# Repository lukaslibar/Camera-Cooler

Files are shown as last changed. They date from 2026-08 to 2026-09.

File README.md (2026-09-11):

# Camera Cooler
Cooling solution for Svbony SV705C astronomy camera.

More about the project on my [website](https://luka.slibar.si/project.html?id=project1).

---

This repository contains multiple components, each under its own license.

- Firmware - GPL-3.0
- Hardware - CERN-OHL-S-2.0
- Software - GPL-3.0

See the ***project-folder/LICENSES*** directory for the full license texts.

---

This project is an attempt to actively cool the Svbony SV7505C astronomy camera. The cooling is intended to achieve better image quality by cooling the camera sensor through the bottom PCB. With this setup, we have achieved a temperature difference of 20°C, but we are still trying to improve the results through better insulation. A major problem is condensation, and great care must be taken to avoid short circuits on the camera's bottom PCB. The PCB manufactured by **JLCPCB** can either be placed upside down or sealed with rubber or a similar material. The cooling system is powered by a 19V DC power supply capable of supplying at least 6 A of current.

We are currently developing the REV B PCB, which will eliminate some issues with incorrect connectors (fen connectors) and add the ability to completely disable the Peltier element (TEC) (with an additional MOSFET). At the moment, there are MicroPython example programs for controlling the device, but we are developing a C++ driver to make the system faster and more efficient. There is also a simple GUI, but the USB port currently needs to be configured manually.

**PROBLEMS:**
- ~~Only 20°C of temperature difference(?broken TEC? Possible solution: change the TEC)~~ **with new TEC about 25°C*
- Condensation is accumulating after long periods of runing the device(Possible solution: improve insulation, heat the other side of the camera)
- ~~Slow response time (Possible solution: rewrite the driver in C++)~~  **still needs tuning*
- Noisy fan (Possible solution: change it for a slower fan or a Noctua fan)
- TEC always on (Solution: REV B of the PCB will have an ability to completely power it off)
- Openings on the camera-cooler.stl part are too small and so are hard to print (Solution: thicken them or copletely remove them)

---

## Instructions
### Tools
- PCB Assembly: hot air gun, soldering iron, solder paste, soldering wire, flux
- Whole assembly: 3d printer, screwdrivers (philips, inbus)

### Additional Parts (not on the PCB)
**TEC**
- 15V 5A Paltier element (TEC) 40mm square

**FANS**
- S4028-15K (**12V 40mm 4pin PC connector** (any simmilar fan will also work)) (to cool the heatsink)
- Generic **12V 40mm 2/3/4pin 10mm height** fan (to cool the enclosure) 

**HEATSINKS**
- 25×34×12mm TO-220 heatsink *(to cool the buck converter (XL4016E1) that powers the TEC)* [link](https://www.aliexpress.com/item/1005005843184927.html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)
- Aluminium motherboard heatsink for a 40mm fan [link](https://www.aliexpress.com/item/1005009277375992.html?spm=a2g0o.order_list.order_list_main.95.6b821802gXbK9t)

**THERMAL PAD AND PASTE**
- 100x100mm 1.0mm thick pad [link](https://www.aliexpress.com/item/32988894487.html?spm=a2g0o.order_list.order_list_main.55.6b821802gXbK9t)
- PC thermal paste

**THERMOMETER**
- DS18B20 (**2 are already in the BOM** but only one is currently integrated)

 **INTERFACE**
- **19V 6A** (at least) DC Power Supply with **2.54mm** barrel jack *(for power)* [link](https://www.aliexpress.com/item/1005004085574495.html?spm=a2g0o.order_list.order_list_main.90.6b821802gXbK9t)
- USB-C cable (for data and programming)
- **26 pin 0.5mm pitch 20cm** FFC(felxible flat cable) forward direction *(to inteface between two camera PCBs)* [link](https://www.aliexpress.com/item/1005008474655738.html?spm=a2g0o.order_list.order_list_main.60.6b821802gXbK9t)
- **3 pin-J Micro JST XH 2.54mm pitch** male plug with wire *(to connect the thermometer to the PCB)* [link](https://www.aliexpress.com/item/1005007107123815.html?spm=a2g0o.order_list.order_list_main.65.6b821802gXbK9t)

**SCREWS**
- **Screws:** 16 x M3x4 *(2 screws from the Svbony camera can be reused here, the other 2 are used to mount the camera-cooler.stl to the camera)*, 2/4 x M5x10 *(2 are sufficient, for mounting the enclosure fan)*, 2/4 x M5x47 *(2 are sufficient, for mounting the main fan to the heatsink)*, 7 x M2x5 *(to hold down both PCBs)*
- **Threaded inserts:** 16 x M3x5

### PCB
PCB assembly is quite straightforward. The only exception is soldering the XL4016E1 and its heatsink. They should first be screwed together with a small amount of thermal pad or thermal paste between them. The assembly should then be placed on the PCB and soldered in place at the same time to prevent misalignment.

### Assembly
First, the camera needs to be disassembled. Its top cover and upper PCB, which is connected with a short ribbon cable, need to be removed. The aluminium cooling block and the 3D-printed cooling block holder can then be assembled. The 3d printed parts screwholes should be inserted with threaded inserts with a soldering iron or simmilar tool.

Place a thermal pad on the smaller side of the cooling block. The thermal pad should be cut to the same shape as that side of the block. There is a small hole on the side of the block for the temperature sensor, which must have wires soldered to it. A longer ribbon cable should be connected to the bottom PCB. A small amount of thermal paste can be applied between the temperature sensor and the cooling block to ensure more accurate temperature readings.

The entire assembly can now be fitted into the camera enclosure so that the screw holes are properly aligned. The main fan and heatsink can then be screwed together, and the fan cable can be routed through the upper hole into the PCB enclosure. The complete fan and heatsink assembly can then be fitted into the main enclosure.

The Peltier element (TEC) needs to be fitted to the bottom of the heatsink, with thermal paste applied between the two surfaces. There are holes for its wires alongside a slit for the longer ribbon cable. The camera and the cooler can then be joined together using thermal paste between their contact surfaces. The upper camera PCB and the custom TEC driver PCB have designated positions inside the enclosure on the side. An additional fan can also be installed to cool the enclosure.

---

### Electrical Connections
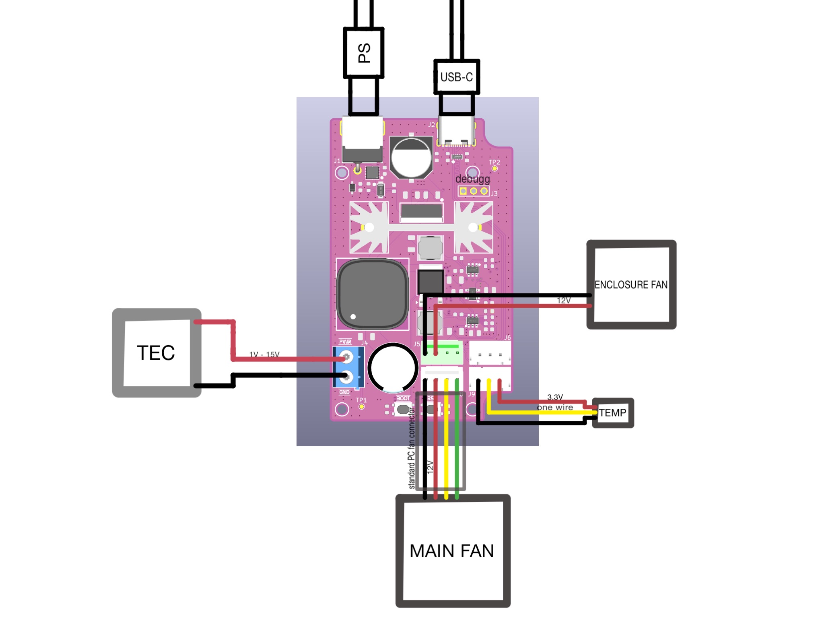
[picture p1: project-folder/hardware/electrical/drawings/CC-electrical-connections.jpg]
TEC driver electrical connections

*TEC driver electrical connections*

---

### Mechanical Assembly
Assembly of 3d printed parts
*Assembly of 3d-printed parts and pcb*

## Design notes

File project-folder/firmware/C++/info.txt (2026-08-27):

The programmes require Raspberry Pico SDK to compile.
Information on how to setup the SDK on:
https://pip-assets.raspberrypi.com/categories/610-raspberry-pi-pico/documents/RP-008276-DS-2-getting-started-with-pico.pdf

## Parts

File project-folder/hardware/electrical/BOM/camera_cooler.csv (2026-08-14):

Reference | Qty | Value | DNP | Exclude from BOM | Exclude from Board | LCSC | Manufacturer | Mauser | Part | Description
C1,C12 | 2 | 22u |  |  |  | C7432786 | Chinocera |  | HGC1206R5226M250NSPJ | 22uF ±20% 25V Ceramic Capacitor X5R 1206
C2,C3,C4,C5,C6,C10,C14,C21,C22,C23,C24,C25,C26,C27,C28,C29,C30,C31,C32,C33,C43 | 21 | 100n |  |  |  | C6119867 | muRata |  | CGA0603X7R104K500JT | 100nF ±10% 50V Ceramic Capacitor X7R 0603
C7 | 1 | 4.7u |  |  |  | C77096 | muRata |  | GRM31CR71H475KA12L | 4.7uF ±10% 50V Ceramic Capacitor X7R 1206
C8,C9,C13,C34,C44,C45,C46 | 7 | 10u |  |  |  | C440198 | muRata |  | GRM21BR61H106KE43L | 10uF ±10% 50V Ceramic Capacitor X5R 0805
C11 | 1 | 47p |  |  |  | C5137501 | FOJAN |  | FCC0603N470J500CT | 47pF ±5% 50V Ceramic Capacitor C0G 0603
C15,C16,C19,C20 | 4 | 4.7u |  |  |  | C19666 | Samsung Electro-Mechanics |  | CL10A475KO8NNNC | 4.7uF ±10% 16V Ceramic Capacitor X5R 0603
C17,C18 | 2 | 15p |  |  |  | C519483 | YAGEO |  | CC0603FRNPO9BN150 | 15pF ±1% 50V Ceramic Capacitor NP0 0603
C36,C37,C41 | 3 | 1u |  |  |  | C1848 | Samsung Electro-Mechanics |  | CL31B105KBHNNNE | 1uF ±10% 50V Ceramic Capacitor X7R 1206
C38 | 1 | 470u |  |  |  | C22469994 | FOLLON |  | EFVM050ADA471M10C0 | 470uF ±20% 50V Aluminum Electrolytic Capacitors
C39 | 1 | 33n |  |  |  | C21117 | Samsung Electro-Mechanics |  | CL10B333KB8NNNC | 33nF ±10% 50V Ceramic Capacitor X7R 0603
C40 | 1 | 1000u |  |  |  | C88743 | rubycon |  | 35YXJ1000M12.5X20 | 1000uF 35V Aluminum Electrolytic Capacitors Through Hole,D12.5xL20mm 10000hrs@105℃
D1 | 1 | PESD1IVN24-AX |  |  |  | C503381 | Nexperia |  | PESD1IVN24-AX | 42VC Clamp 3.5A@8/20us Ipp ESD DIODE SOD-323
D2 | 1 | MMSZ4706_C3031903 |  |  |  | C3031903 | CJ |  | MMSZ4706 | Zener Diode Independent 19V 500mW Surface Mount SOD-123
D3 | 1 | TPD4E05U06DQAR_C2827646 |  |  |  | C2827646 | TECH PUBLIC |  | TPD4E05U06DQAR | 13VC Clamp 5A Ipp ESD DIODE USON-10(1x2.5)
D4 | 1 | MBR2045DCT |  |  |  | C42402358 | BORN |  | MBR2045DCT | Diode 45V 20A Surface Mount TO-252
J1 | 1 | DC-044K-D025 |  |  |  | C963204 | G-Switch |  | DC-044K-D025 | Power Barrel Connector Jack 2.5mm ID 6mm OD Through Hole, Right Angle
J2 | 1 | TYPE-C 16PIN 2MD |  |  |  | C2765186 | SHOU HAN(首韩) |  | TYPE-C 16PIN 2MD(073) | USB-C (USB TYPE-C) Receptacle Connector 16 Position Surface Mount, Right Angle
J4 | 1 | KF301-5.0-2P |  |  |  | C474881 | KEFA |  | KF301-5.0-2P | 2 Position Wire to Board Terminal Block Through Hole 5mm
J5,J8 | 2 | 2510-4A |  |  |  | C2847671 | CAX |  | 2510-4A | Connector Header 4 position 2.54mm Pitch 3A Through Hole -25℃~+85℃
J6,J9 | 2 | ZX-XH2.54-3PZZ |  |  |  | C7429633 | Megastar |  | ZX-XH2.54-3PZZ | Connector Header 3 position 2.5mm Pitch 3A Through Hole -25℃~+85℃
L1 | 1 | 22u |  |  |  | C780213 | BOURNS |  | SRN6045-220M | 1.5A 22uH 142mΩ 1.9A ±20% SMD,6x6mm Fixed Inductors RoHS
L2 | 1 | 10u |  |  |  | C476261 | BOURNS |  | SRN6045-100M | 2.5A 10uH 3A 58.6mΩ ±20% SMD,6x6mm Fixed Inductors RoHS
L3 | 1 | 3.3u |  |  |  | C42411119 | ABRACON |  | AOTA-B201610S3R3-101-T | 2.1A 3.3uH 115mΩ 2.4A Molded Inductor 0806 Fixed Inductors RoHS
L4 | 1 | 47u |  |  |  | C5119635 | PROD |  | PDPMAA1712-470MP | 8A 47uH ±20% 32mΩ 14A Through Hole,P=13mm Fixed Inductors RoHS
Q1 | 1 | DMP3013SFV-7 |  |  |  | C264098 | Diodes |  | DMP3013SFV-7 | P-Channel 30V 35A 1.94W Surface Mount PowerDI3333-8
Q2,Q3 | 2 | 2N7002LT1G |  |  |  | C16338 | onsemi |  | 2N7002LT1G | N-Channel 60V 115mA 225mW Surface Mount SOT-23
R1 | 1 | 88.7k |  |  |  | C23258 | UNI-ROYAL |  | 0603WAF8872T5E | 88.7kΩ ±1% 100mW 0603 Thick Film Resistor
R2 | 1 | 22.1k |  |  |  | C2960862 | FOJAN |  | FRC0603F2212TS | 22.1kΩ ±1% 100mW 0603 Thick Film Resistor
R3,R8,R9,R15,R16 | 5 | 12k |  |  |  | C2907097 | FOJAN |  | FRC0603J123 TS | TS 12kΩ ±5% 100mW 0603 Thick Film Resistor
R4,R30,R33 | 3 | 100k |  |  |  | C2906980 | FOJAN |  | FRC0603F1003TS | 100kΩ ±1% 100mW 0603 Thick Film Resistor
R5 | 1 | 5.23k |  |  |  | C23068 | UNI-ROYAL |  | 0603WAF5231T5E | 5.23kΩ ±1% 100mW 0603 Thick Film Resistor
R6,R10,R13,R14 | 4 | 5.1k |  |  |  | C2907044 | FOJAN |  | FRC0603F5101TS | 5.1kΩ ±1% 100mW 0603 Thick Film Resistor
R7 | 1 | 33 |  |  |  | C2909394 | FOJAN |  | FRC0603F33R0TS | 33Ω ±1% 100mW 0603 Thick Film Resistor
R11,R12 | 2 | 27 |  |  |  | C2907021 | FOJAN |  | FRC0603F27R0TS | 27Ω ±1% 100mW 0603 Thick Film Resistor
R17,R18,R19 | 3 | 1k |  |  |  | C2907002 | FOJAN |  | FRC0603F1001TS | 1kΩ ±1% 100mW 0603 Thick Film Resistor
R20,R22 | 2 | 10 |  |  |  | C2906983 | FOJAN |  | FRC0603F10R0TS | 10Ω ±1% 100mW 0603 Thick Film Resistor
R21 | 1 | 2m |  |  |  | C46634447 | JIERR |  | JER2512F3R002 | 3W 2mΩ ±50ppm/℃ ±1% 2512 Chip Resistor - Surface Mount RoHS
R23 | 1 | 180k |  |  |  | C2906999 | FOJAN |  | FRC0603F1803TS | 180kΩ ±1% 100mW 0603 Thick Film Resistor
R24 | 1 | 43k |  |  |  | C2907038 | FOJAN |  | FRC0603F4302TS | 43kΩ ±1% 100mW 0603 Thick Film Resistor
R25,R27 | 2 | 0 |  |  |  | C2906974 | FOJAN |  | FRC0603F0000TS | 100mW 0Ω 75V Thick Film Resistor ±1% 0603 Chip Resistor - Surface Mount RoHS
R26 | 1 | 27k |  |  |  | C2930084 | FOJAN |  | FRC0603F2702TS | 27kΩ ±1% 100mW 0603 Thick Film Resistor
R28,R29,R31,R32 | 4 | 100 |  |  |  | C2906981 | FOJAN |  | FRC0603F1000TS | 100Ω ±1% 100mW 0603 Thick Film Resistor
SW1,SW2 | 2 | TS3425BA |  |  |  | C2681476 | SHOU HAN |  | TS3425BA | Tactile Switch SPST 250gf 2.5mm J-Lead 4.2mm x 3.2mm Surface Mount
U1,U2 | 2 | DS18B20 |  |  | Excluded from board | C9753 | MAXIM |  | DS18B20+ | -55℃~+125℃ ±0.5℃ Single bus 3V~5.5V TO-92 Analog and Digital Output RoHS
U4 | 1 | TPS560430XDBVR |  |  |  | C524782 | TI |  | TPS560430XDBVR | 1.1MHz Buck Adjustable 600mA 1V~34.2V SOT-23-6 Voltage Regulators - DC DC Switching Regulators RoHS
U5 | 1 | TLV75533PDBVR |  |  |  | C404027 | TI |  | TLV75533PDBVR | 3.3V Positive Fixed SOT-23-5 Voltage Regulators - Linear, Low Drop Out (LDO) Regulators RoHS
U6 | 1 | TPS54202DDCR |  |  |  | C191884 | TI |  | TPS54202DDCR | 500kHz Buck Adjustable 2A SOT-23-6 Voltage Regulators - DC DC Switching Regulators RoHS
U7 | 1 | RP2354A |  |  |  | C41378174 | Raspberry Pi |  | RP2354A | QFN-60(7x7) Microcontrollers RoHS
U8 | 1 | ABM8-272-T3_C20625731 |  |  |  | C20625731 | ABRACON |  | ABM8-272-T3 | ±30ppm 10pF ±30ppm SMD3225-4P Crystals RoHS
U9 | 1 | INA219AIDR |  |  |  | C138706 | TI |  | INA219AIDR | 0V~26V 10uV 20nA 1 SOIC-8 Current Regulation/Management RoHS
U10 | 1 | XL4016E1 |  |  |  | C55881 | XLSEMI |  | XL4016E1 | Buck Switching Regulator IC Adjustable 1.25V~32V 1 Output 12A TO-220-5
U11 | 1 | MCP4725A0T-E/CH |  |  |  | C144198 | MICROCHIP |  | MCP4725A0T-E/CH | 6us 2.7V~5.5V 2LSB I2C SOT-23-6 Digital to Analog Converters (DAC) RoHS

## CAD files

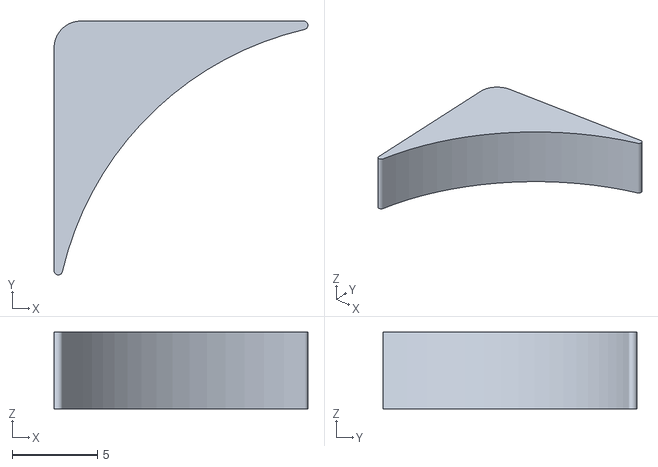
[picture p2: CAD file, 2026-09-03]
project-folder/hardware/mechanical/3d-printed/fan-spacer-TPU.STL
14.9 x 14.9 x 4.50

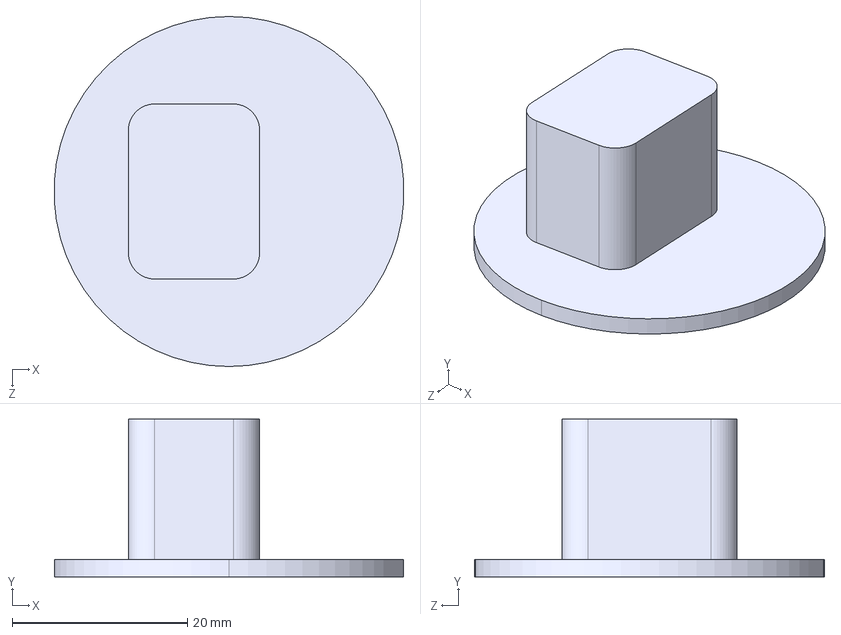
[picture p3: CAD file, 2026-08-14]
project-folder/hardware/mechanical/CNC/cooling_block_V2.STEP
39.9 x 18.0 x 40.0 mm

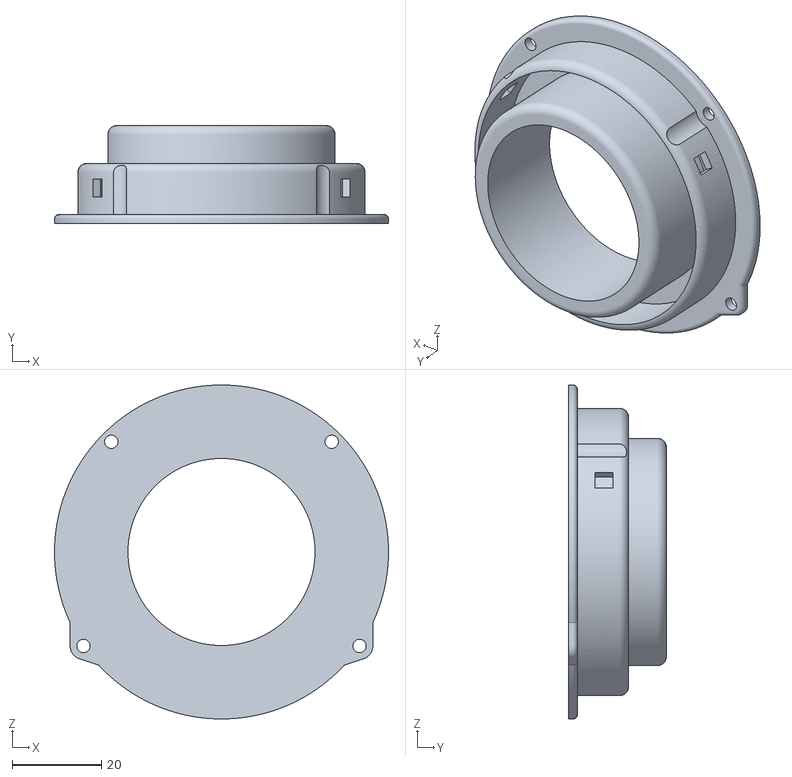
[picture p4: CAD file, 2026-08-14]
project-folder/hardware/mechanical/3d-printed/connection-mount.STL
75.0 x 22.0 x 75.0

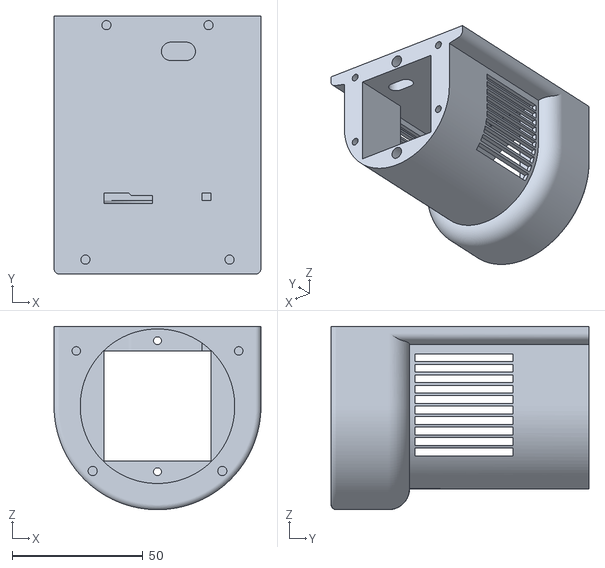
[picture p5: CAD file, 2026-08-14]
project-folder/hardware/mechanical/3d-printed/camera-cooler.STL
79.0 x 98.5 x 70.0

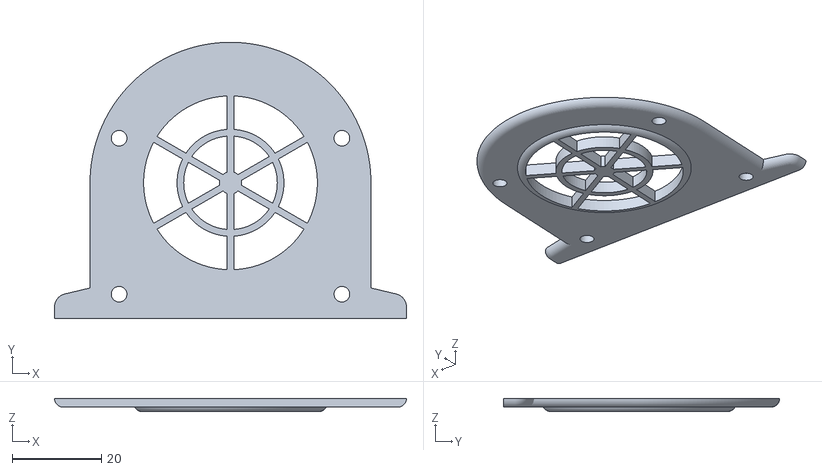
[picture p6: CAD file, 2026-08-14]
project-folder/hardware/mechanical/3d-printed/camera-cooler-cover.STL
79.0 x 62.0 x 3.00

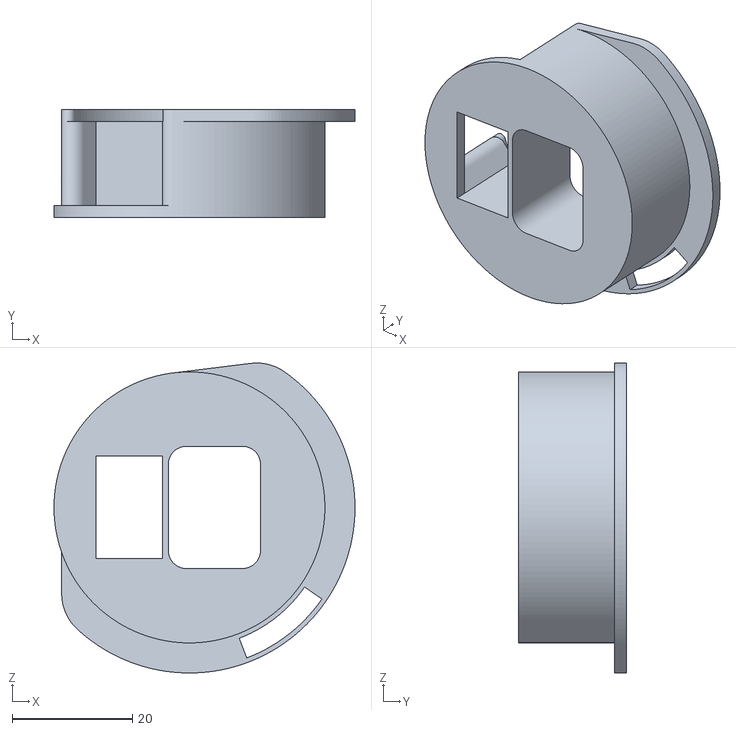
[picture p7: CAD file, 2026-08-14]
project-folder/hardware/mechanical/3d-printed/cooling-block-holder.STL
50.0 x 18.0 x 51.5

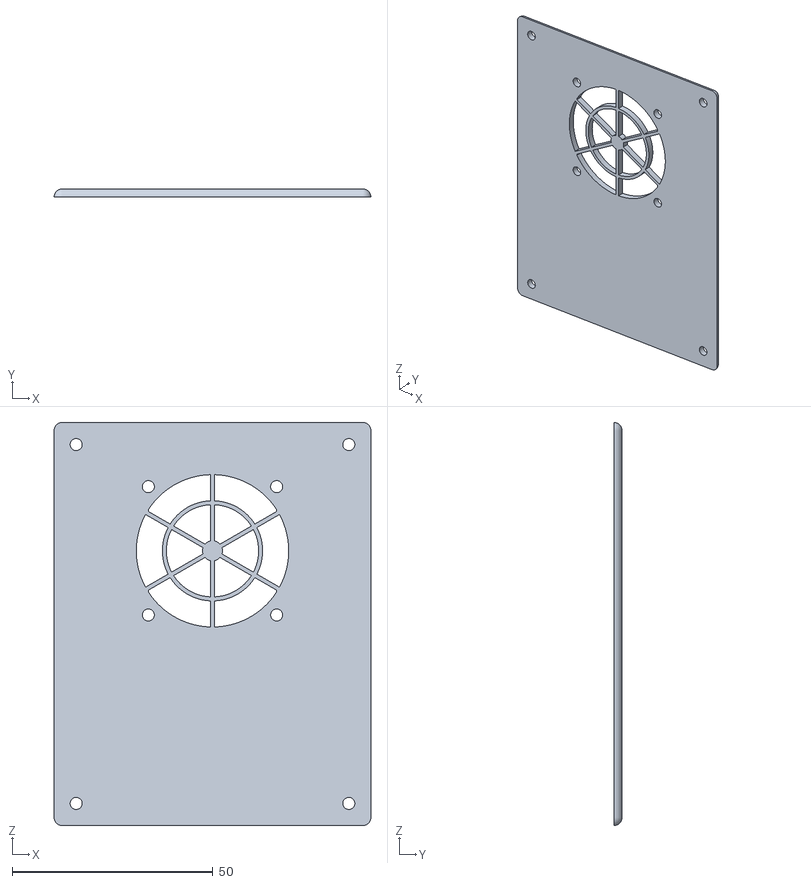
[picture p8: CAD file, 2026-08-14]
project-folder/hardware/mechanical/3d-printed/camera-cooler-enclosure-cover.STL
79.0 x 2.00 x 100.5

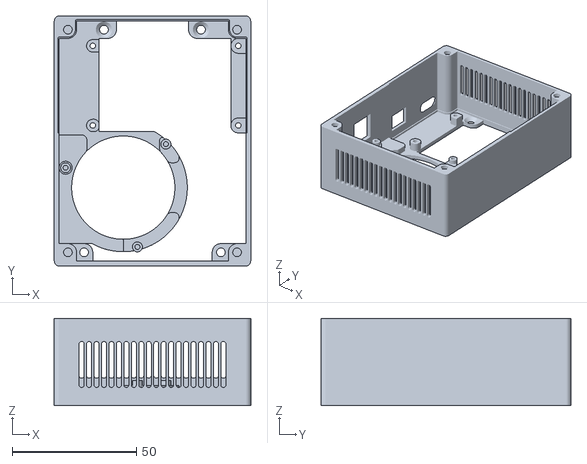
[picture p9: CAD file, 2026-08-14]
project-folder/hardware/mechanical/3d-printed/camera-cooler-enclosure.STL
79.0 x 100.5 x 35.0

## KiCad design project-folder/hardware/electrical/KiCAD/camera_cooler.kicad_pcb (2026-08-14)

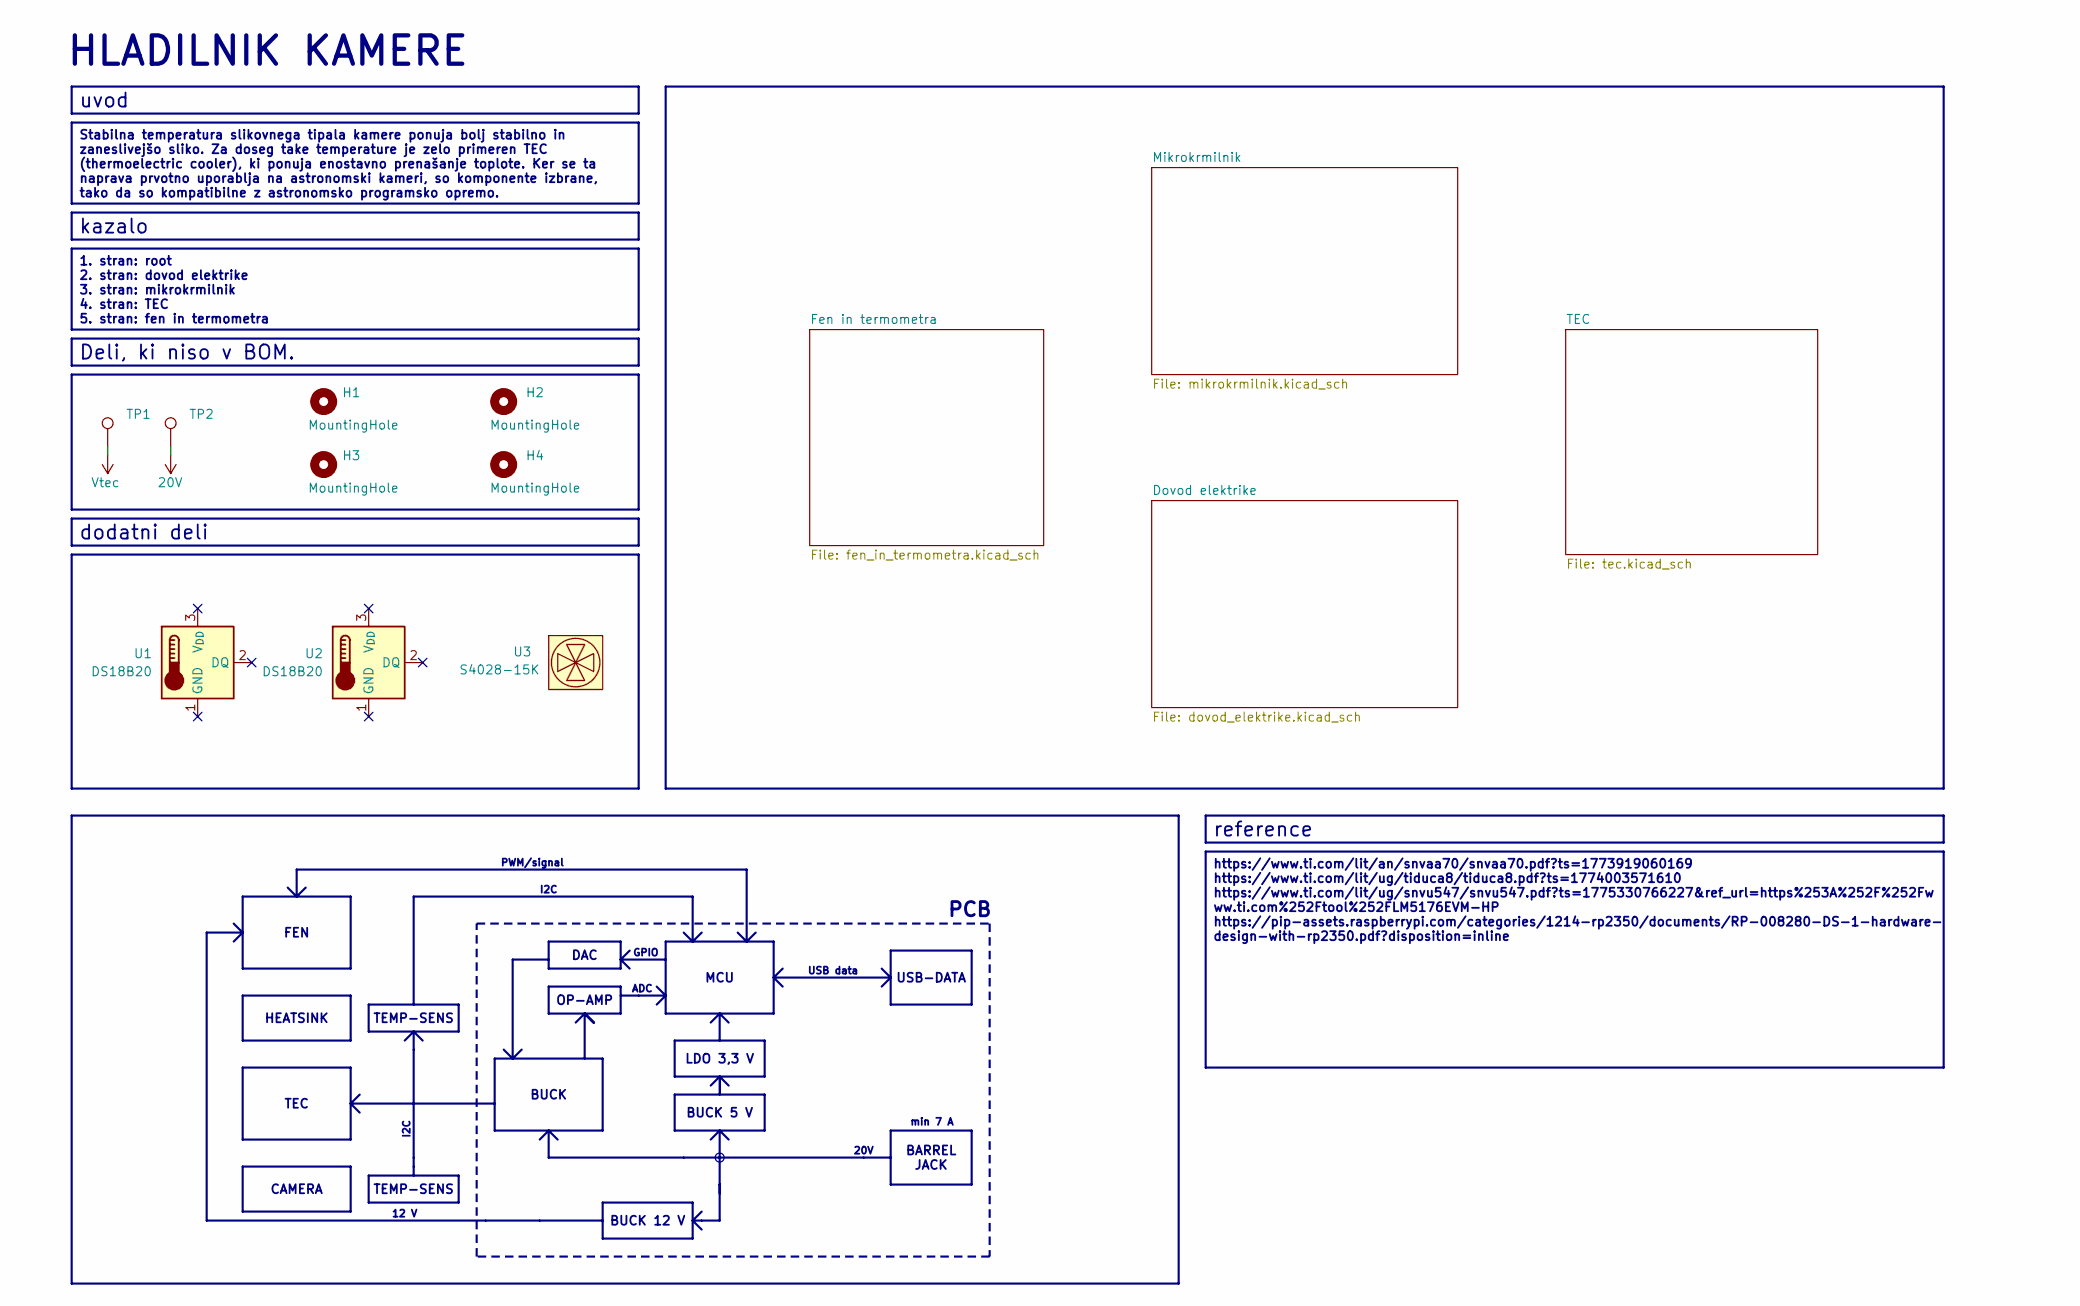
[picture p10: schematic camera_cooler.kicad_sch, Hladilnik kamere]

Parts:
H1, H2, H3, H4: MountingHole; MountingHole_2.2mm_M2
TP1, TP2: TestPoint; TestPoint_Pad_D1.0mm
U1, U2: DS18B20; TO-92_Inline; Part DS18B20+; LCSC C9753
U3: S4028-15K; Part S4028-15K

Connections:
20V: TP2.1; also elsewhere on the board
Vtec: TP1.1; also elsewhere on the board

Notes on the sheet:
GPIO
PCB
USB data
HLADILNIK KAMERE
min 7 A
20V
PWM/signal
I2C
12 V
ADC
MCU
reference
TEC
BUCK 12 V
FEN
HEATSINK
1. stran: root 2. stran: dovod elektrike 3. stran: mikrokrmilnik 4. stran: TEC 5. stran: fen in termometra
BUCK 5 V
BARREL JACK
https://www.ti.com/lit/an/snvaa70/snvaa70.pdf?ts=1773919060169 https://www.ti.com/lit/ug/tiduca8/tiduca8.pdf?ts=1774003571610 https://www.ti.com/lit/ug/snvu547/snvu547.pdf?ts=1775330766227&ref_url=https%253A%252F%252Fw ww.ti.com%252Ftool%252FLM5176EVM-HP https://pip-assets.raspberrypi.com/categorie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
Stabilna temperatura slikovnega tipala kamere ponuja bolj stabilno in zaneslivejšo sliko. Za doseg take temperature je zelo primeren TEC (thermoelectric cooler), ki ponuja enostavno prenašanje toplote. Ker se ta naprava prvotno uporablja na astronomski kameri, so komponente izbrane, tako da so komp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
OP-AMP
dodatni deli
Deli, ki niso v BOM.
kazalo
TEMP-SENS
USB-DATA
CAMERA
LDO 3,3 V
BUCK
uvod
DAC

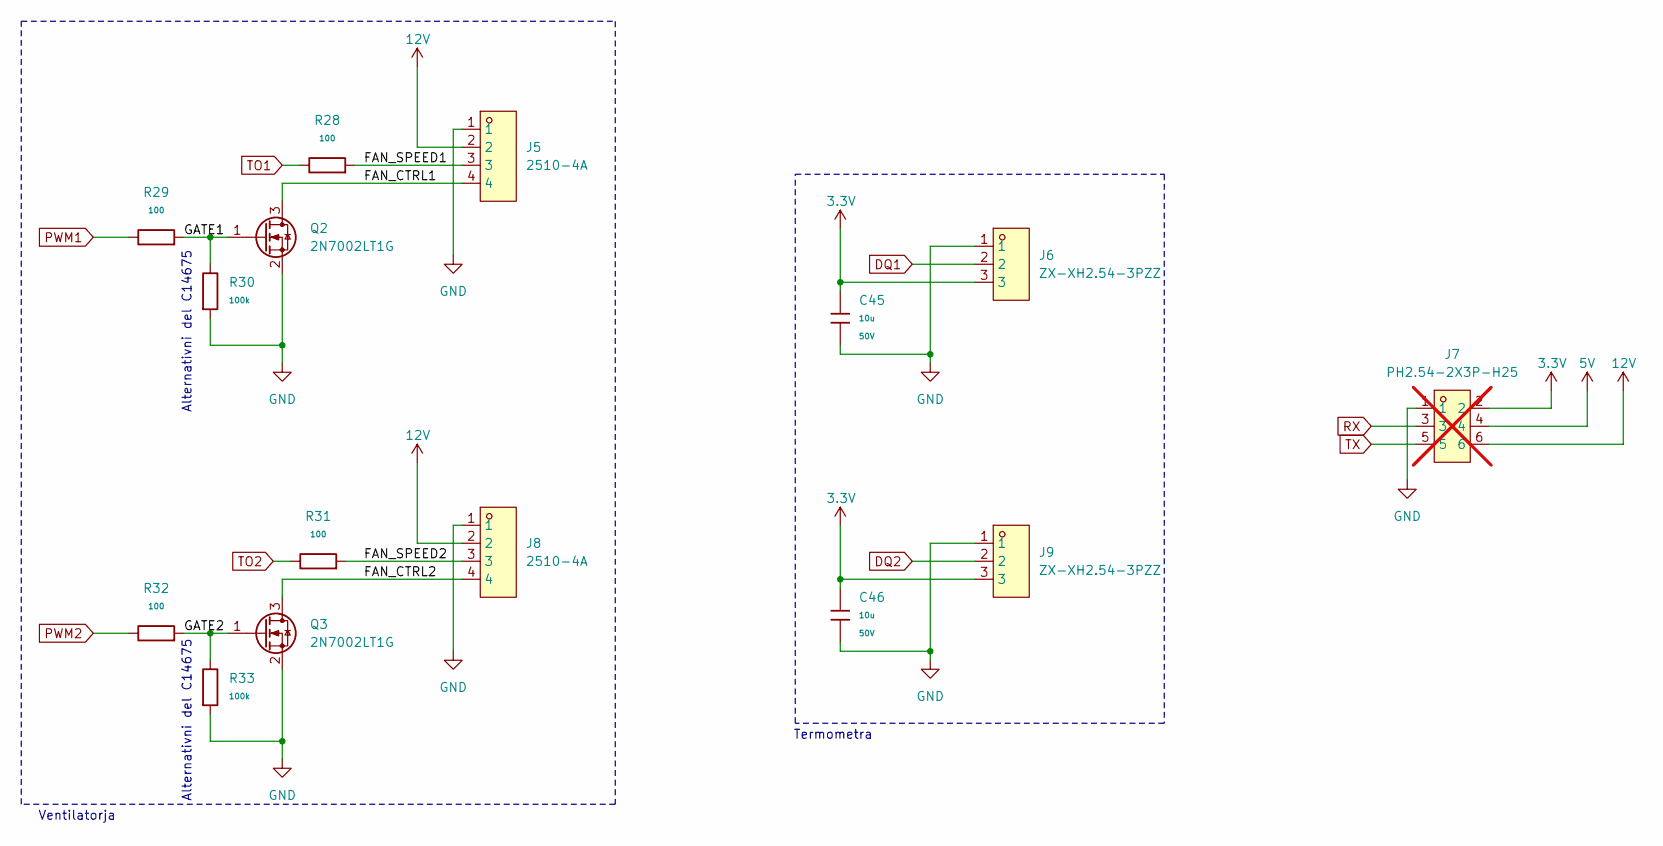
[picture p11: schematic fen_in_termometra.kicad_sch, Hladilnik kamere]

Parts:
C45, C46: 10u; C_0805; Voltage Rated 50V; Part GRM21BR61H106KE43L; LCSC C440198
J5, J8: 2510-4A; CONN-TH_4P-P2.54_CAX_2510-4A; MPN 2510-4A; LCSC Part C2847671
J6, J9: ZX-XH2.54-3PZZ; CONN-TH_3P-P2.54_2501S-3P; MPN ZX-XH2.54-3PZZ; LCSC Part C7429633
J7: PH2.54-2X3P-H25; HDR-TH_6P-P2.54-V-M-R2-C3-S2.54-1; MPN PH2.54-2X3P-H25; LCSC Part C42431837; not fitted
Q2, Q3: 2N7002LT1G; SOT-23; Part 2N7002LT1G; LCSC C16338
R28, R29, R31, R32: 100; R_0603; Part FRC0603F1000TS; LCSC C2906981
R30, R33: 100k; R_0603; Part FRC0603F1003TS; LCSC C2906980

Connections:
3.3V: C45.1, C46.1, J6.3, J7.2, J9.3; also elsewhere on the board
12V: J5.2, J7.6, J8.2; also elsewhere on the board
/Fen in termometra/GATE1: Q2.1 (G), R29.2, R30.1
/Fen in termometra/GATE2: Q3.1 (G), R32.2, R33.1
DQ1: J6.2; also elsewhere on the board
DQ2: J9.2; also elsewhere on the board
GND: C45.2, C46.2, J5.1, J6.1, J7.1, J8.1, J9.1, Q2.2 (S), Q3.2 (S), R30.2, R33.2; also elsewhere on the board
unnamed: J5.3, R28.2
unnamed: J8.3, R31.2
unnamed: J5.4, Q2.3 (D)
unnamed: J8.4, Q3.3 (D)
PWM1: R29.1; also elsewhere on the board
PWM2: R32.1; also elsewhere on the board
TO1: R28.1; also elsewhere on the board
TO2: R31.1; also elsewhere on the board

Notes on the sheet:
Ventilatorja
Alternativni del C14675
Termometra

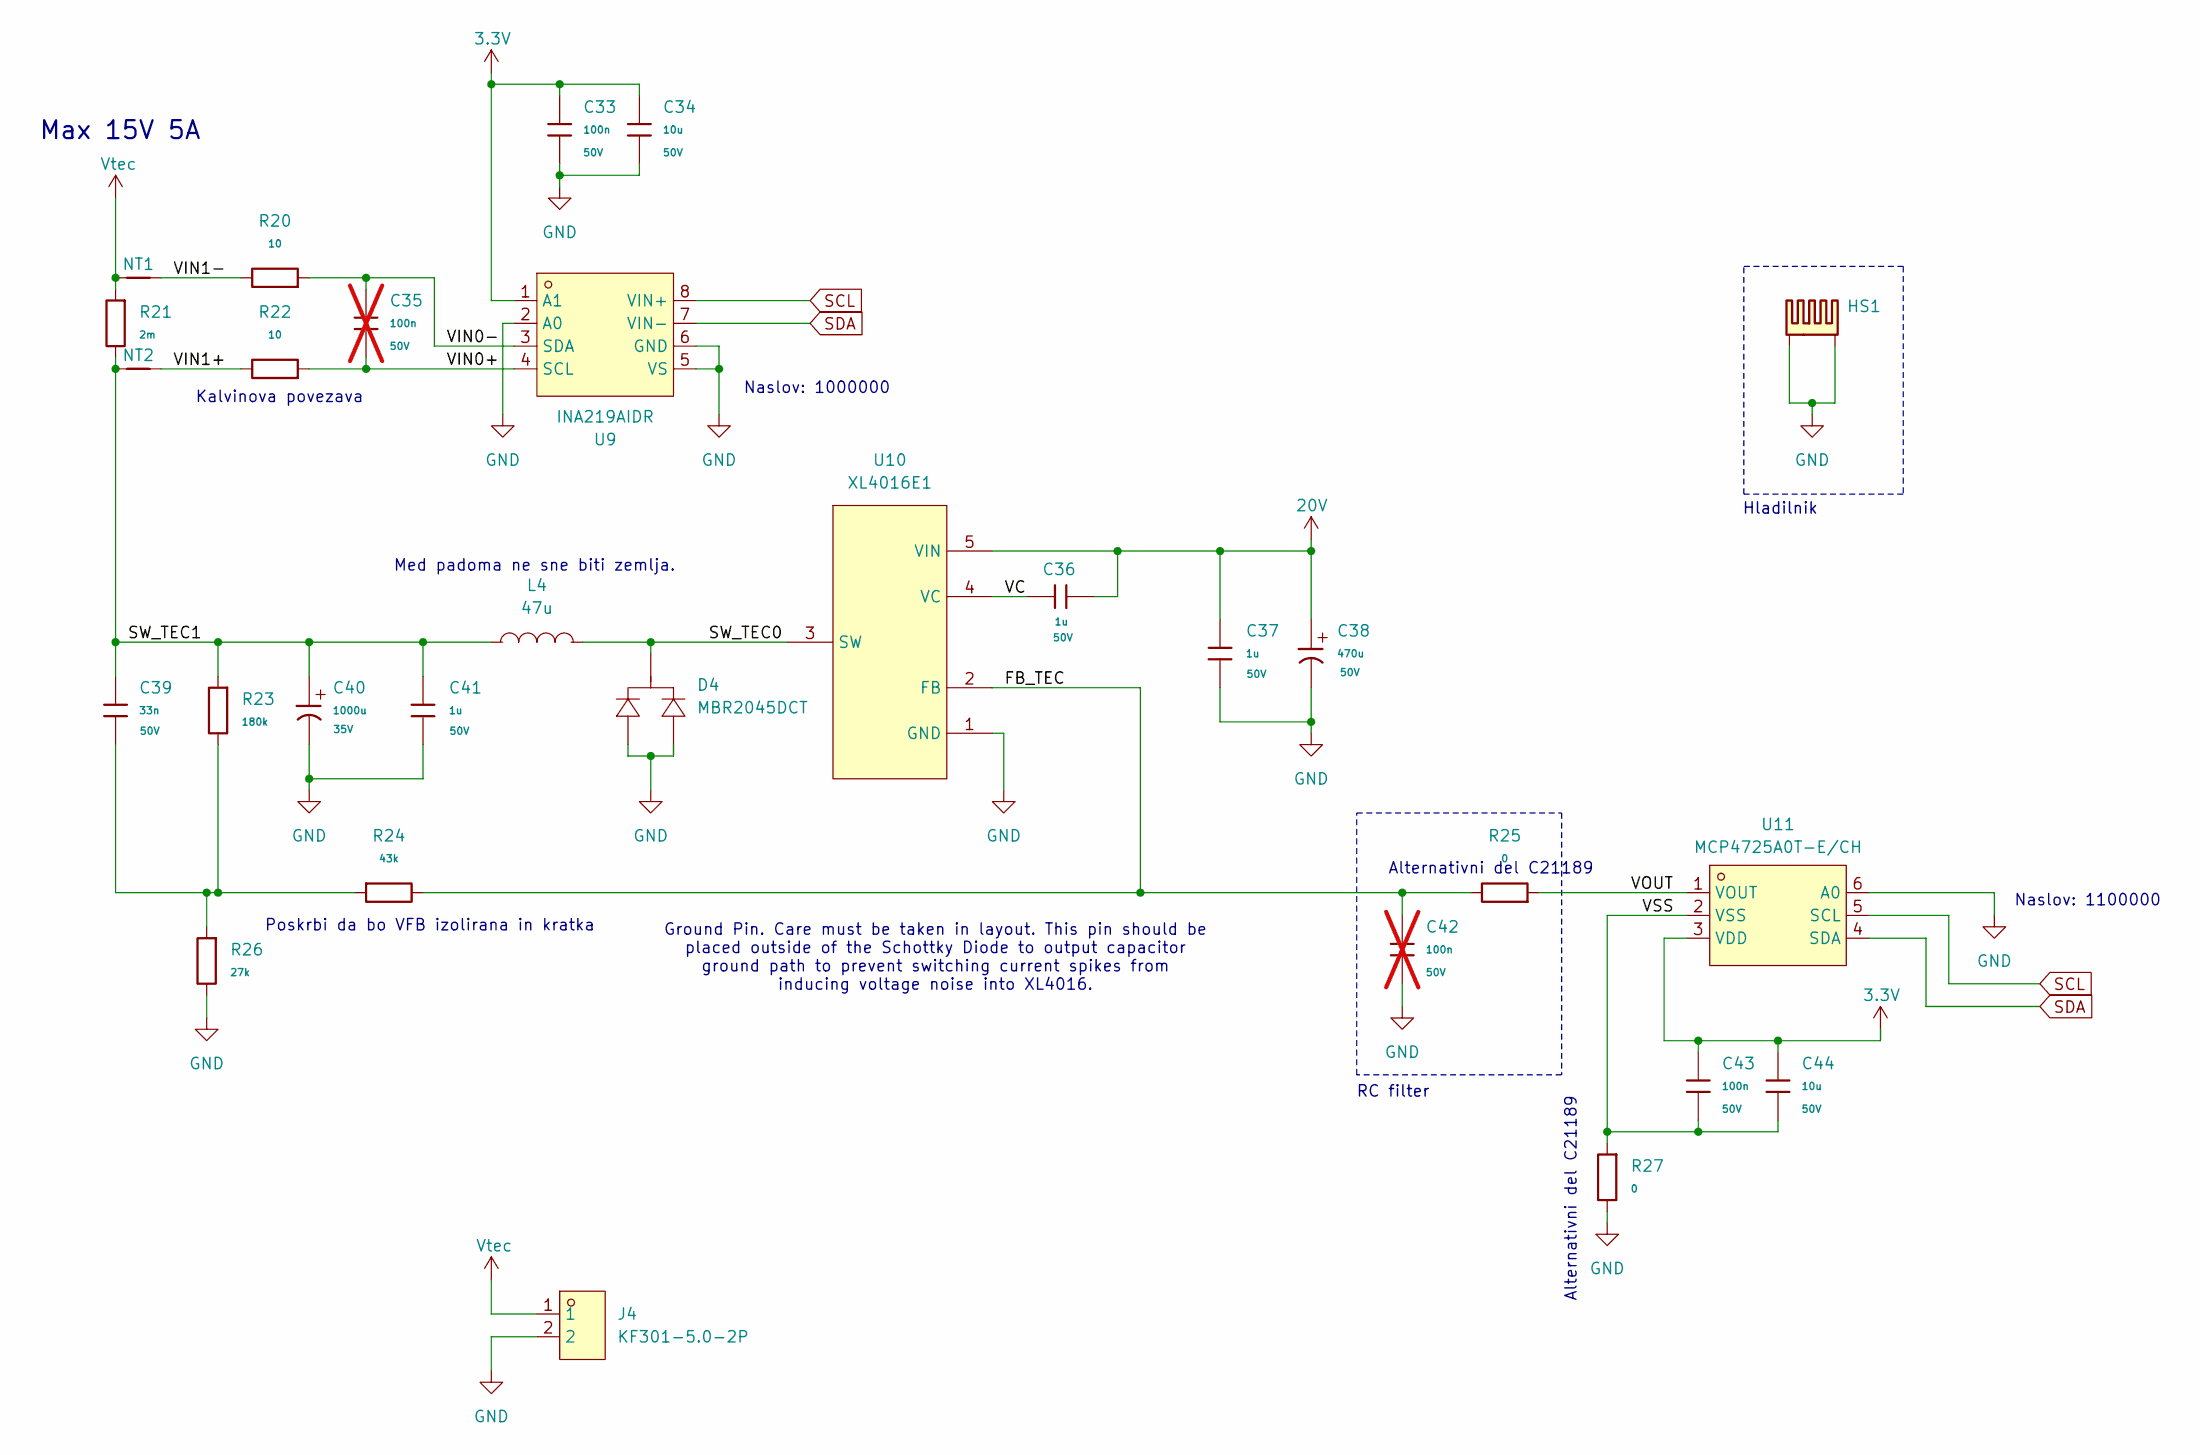
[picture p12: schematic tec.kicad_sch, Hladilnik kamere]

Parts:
C33, C43: 100n; C_0603; Voltage Rated 50V; Part CGA0603X7R104K500JT; LCSC C6119867
C34, C44: 10u; C_0805; Voltage Rated 50V; Part GRM21BR61H106KE43L; LCSC C440198
C35, C42: 100n; C_0603; Voltage Rated 50V; Tolerance ±10%; Part CGA0603X7R104K500JT; LCSC C6119867; not fitted
C36, C37, C41: 1u; C_1206; Voltage Rated 50V; Part CL31B105KBHNNNE; LCSC C1848
C38: 470u; CAP-SMD_BD10.0-L10.4-W10.4-LS11.2-FD; Voltage Rated 50V; Part EFVM050ADA471M10C0; LCSC C22469994
C39: 33n; C_0603; Voltage Rated 50V; Part CL10B333KB8NNNC; LCSC C21117
C40: 1000u; CAP-TH_BD12.5-P5.00-D0.6-FD; Voltage Rated 35V; Part 35YXJ1000M12.5X20; LCSC C88743
D4: MBR2045DCT; TO-252-2; Part MBR2045DCT; LCSC C42402358
HS1: HSE-B20254-035H-01; HSEB20254035H01; Part HSE-B20254-035H-01
J4: KF301-5.0-2P; CONN-TH_P5.00_KF301-5.0-2P; MPN KF301-5.0-2P; LCSC Part C474881
L4: 47u; IND-TH_L17.8-W17.8-P13.00-D0.6; Part PDPMAA1712-470MP; LCSC C5119635
NT1, NT2: NetTie_2; NetTie-2_SMD_Pad0.5mm
R20, R22: 10; R_0603; Part FRC0603F10R0TS; LCSC C2906983
R21: 2m; R_2512_6332Metric; Part JER2512F3R002; LCSC C46634447
R23: 180k; R_0603; Part FRC0603F1803TS; LCSC C2906999
R24: 43k; R_0603; Part FRC0603F4302TS; LCSC C2907038
R25, R27: 0; R_0603; Part FRC0603F0000TS; LCSC C2906974
R26: 27k; R_0603; Part FRC0603F2702TS; LCSC C2930084
U9: INA219AIDR; SOIC-8_L4.9-W3.9-P1.27-LS6.0-BL; MPN INA219AIDR; LCSC Part C138706
U10: XL4016E1; TO-220-5L_L10.2-W4.5-P1.71-L; Part XL4016E1; LCSC C55881
U11: MCP4725A0T-E/CH; SOT-23-6_L2.9-W1.6-P0.95-LS2.8-BL; MPN MCP4725A0T-E/CH; LCSC Part C144198

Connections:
3.3V: C33.1, C34.1, C43.1, C44.1, U9.1 (A1), U11.3 (VDD); also elsewhere on the board
20V: C36.2, C37.1, C38.1, U10.5 (VIN); also elsewhere on the board
/TEC/FB_TEC: C42.1, R24.1, R25.1, U10.2 (FB)
/TEC/SW_TEC0: D4.2, L4.2, U10.3 (SW)
/TEC/SW_TEC1: C39.1, C40.1, C41.1, L4.1, NT2.1, R21.1, R23.2
/TEC/VC: C36.1, U10.4 (VC)
/TEC/VIN0+: C35.2, R22.2, U9.4 (SCL)
/TEC/VIN0-: C35.1, R20.2, U9.3 (SDA)
/TEC/VIN1+: NT2.2, R22.1
/TEC/VIN1-: NT1.2, R20.1
/TEC/VOUT: R25.2, U11.1 (VOUT)
/TEC/VSS: C43.2, C44.2, R27.2, U11.2 (VSS)
GND: C33.2, C34.2, C37.2, C38.2, C40.2, C41.2, C42.2, D4.1, D4.3, HS1.1, HS1.2, J4.2, R26.1, R27.1, U9.2 (A0), U9.5 (VS), U9.6 (GND), U10.1 (GND), U11.6 (A0); also elsewhere on the board
unnamed: C39.2, R23.1, R24.2, R26.2
SCL: U9.8 (VIN+), U11.5 (SCL); also elsewhere on the board
SDA: U9.7 (VIN-), U11.4 (SDA); also elsewhere on the board
Vtec: J4.1, NT1.1, R21.2; also elsewhere on the board

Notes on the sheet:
Ground Pin. Care must be taken in layout. This pin should be placed outside of the Schottky Diode to output capacitor ground path to prevent switching current spikes from inducing voltage noise into XL4016.
Naslov: 1000000
Hladilnik
Naslov: 1100000
Kalvinova povezava
Poskrbi da bo VFB izolirana in kratka
Alternativni del C21189
Med padoma ne sne biti zemlja.
RC filter
Max 15V 5A

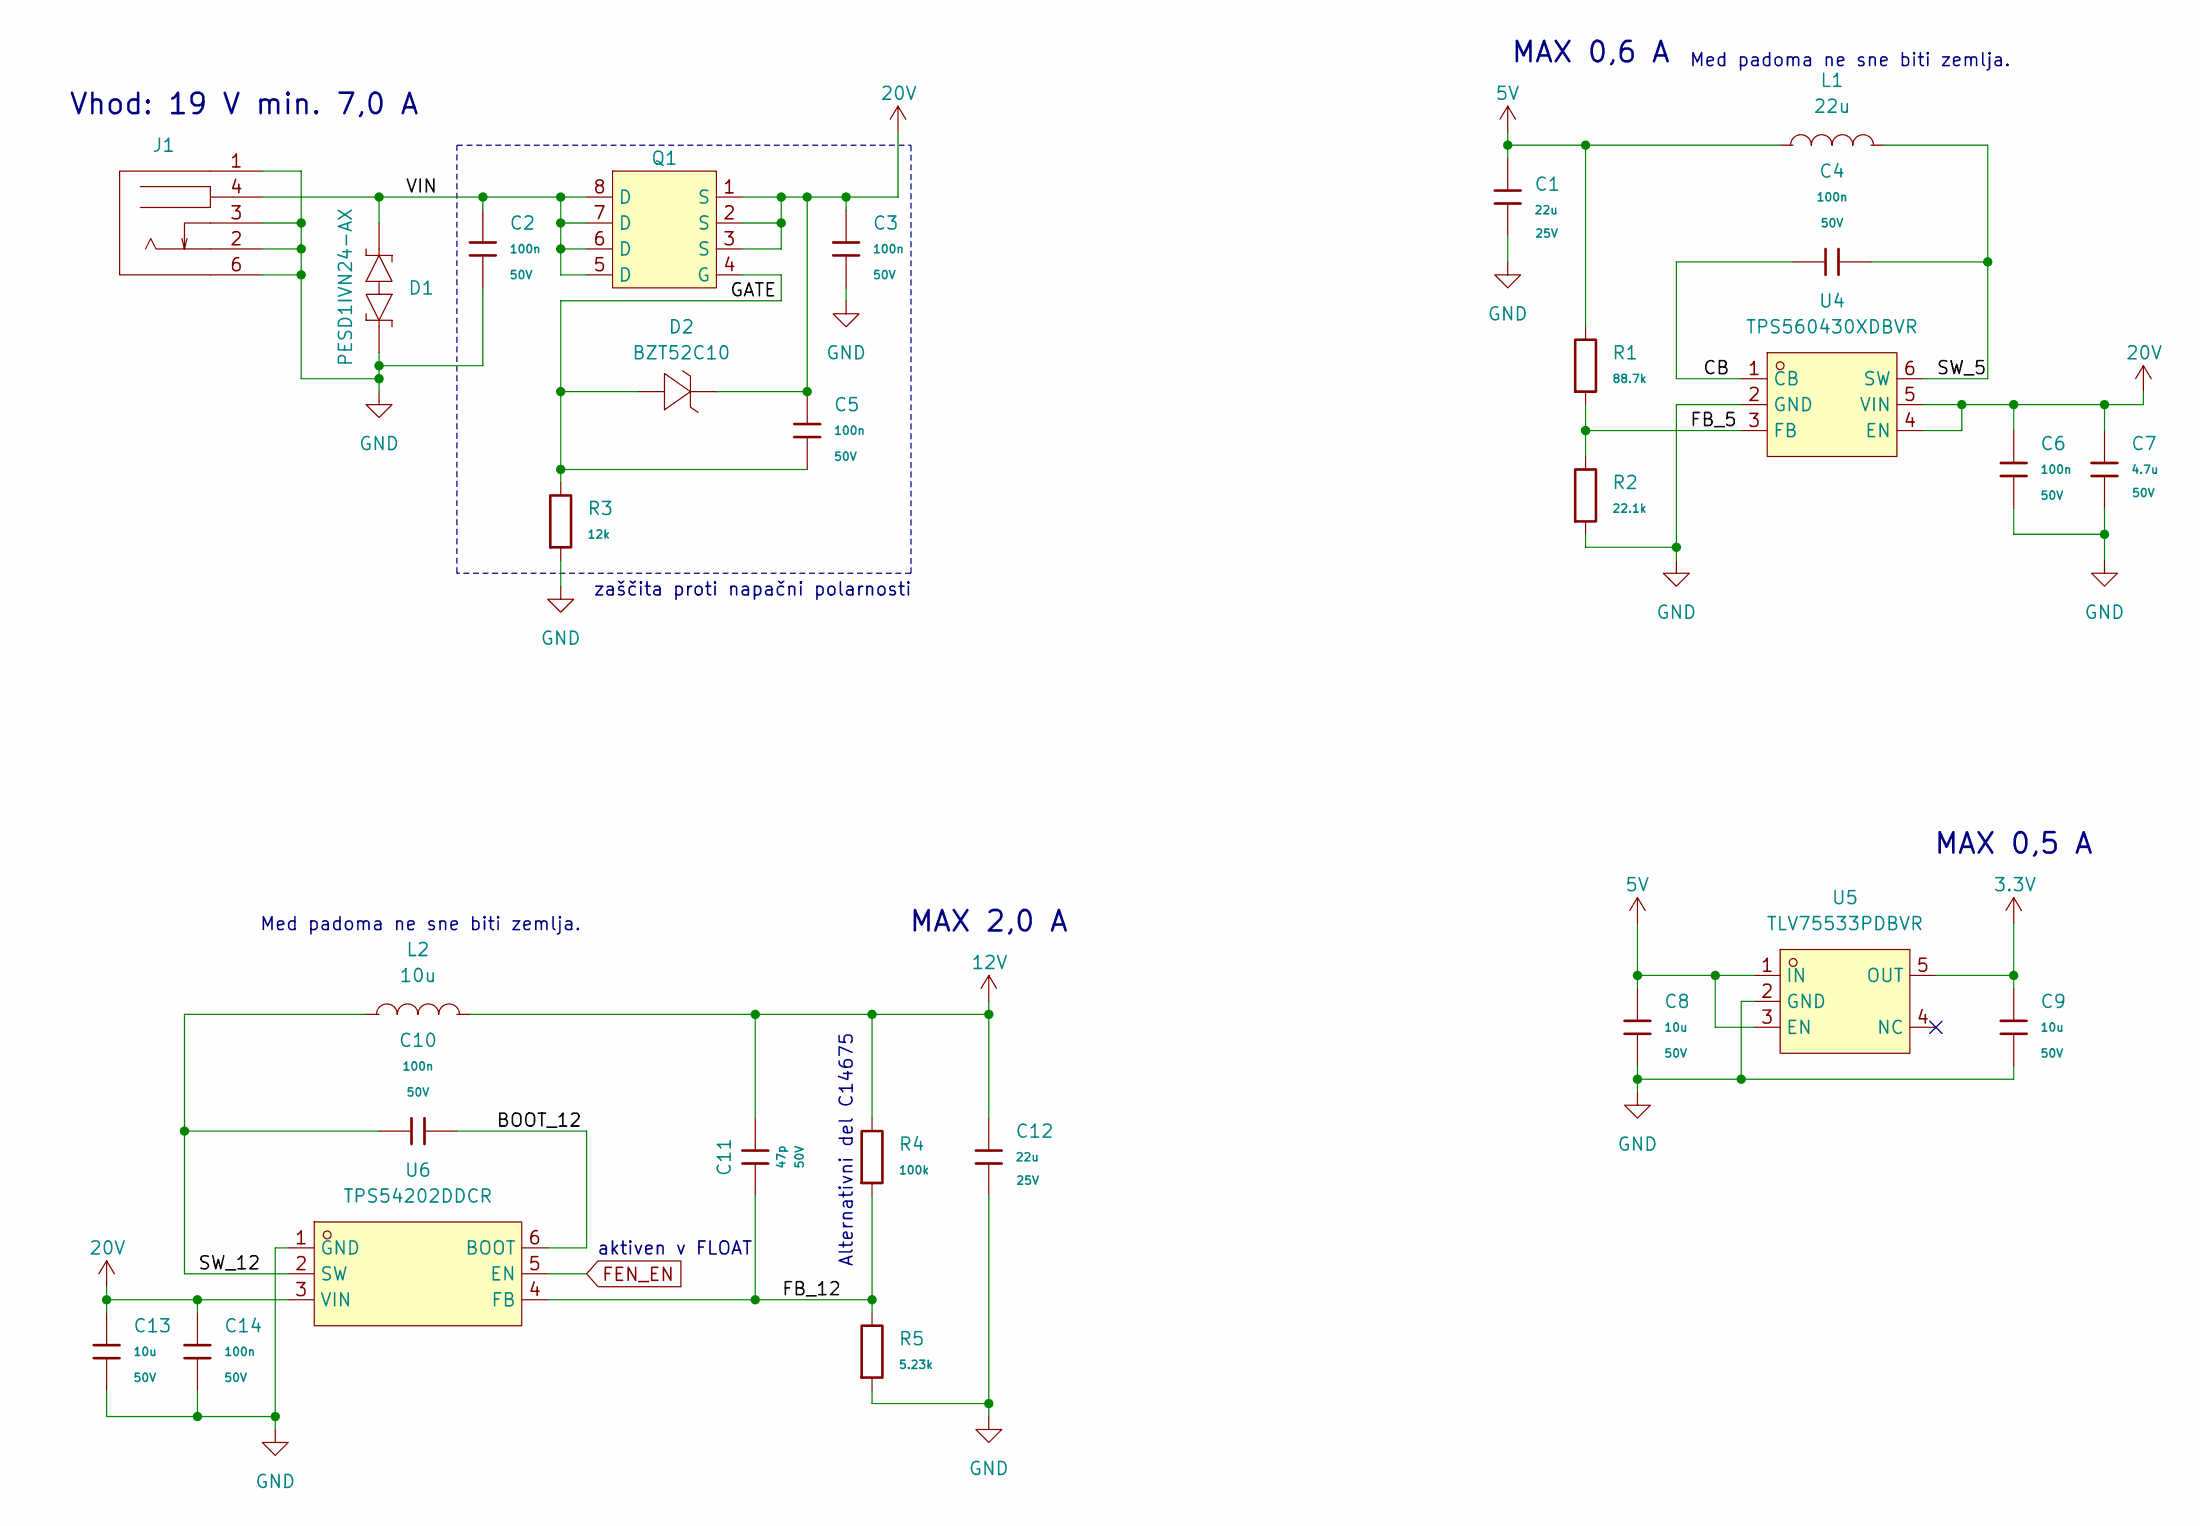
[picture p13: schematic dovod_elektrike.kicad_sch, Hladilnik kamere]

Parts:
C1, C12: 22u; C_1206; Voltage Rated 25V; Part HGC1206R5226M250NSPJ; LCSC C7432786
C2, C3, C4, C5, C10, C14: 100n; C_0603; Voltage Rated 50V; Tolerance ±10%; Part CGA0603X7R104K500JT; LCSC C6119867
C6: 100n; C_0603; Voltage Rated 50V; Part CGA0603X7R104K500JT; LCSC C6119867
C7: 4.7u; C_1206; Voltage Rated 50V; Part GRM31CR71H475KA12L; LCSC C77096
C8, C9, C13: 10u; C_0805; Voltage Rated 50V; Part GRM21BR61H106KE43L; LCSC C440198
C11: 47p; C_0603; Voltage Rated 50V; Part FCC0603N470J500CT; LCSC C5137501
D1: PESD1IVN24-AX; SOD-323_L1.8-W1.3-LS2.5-BI-A; Part PESD1IVN24-AX; LCSC C503381
D2: BZT52C10; SOD-123_L2.7-W1.6-LS3.7-RD; Part BZT52C10; LCSC C173431
J1: DC-044K-D025; DC-IN-TH_DC-044K-D025; Part DC-044K-D025; LCSC Part C963204 Power Barrel Connector Jack 2.5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
L1: 22u; IND-SMD_L6.0-W6.0_SRN6045; Part SRN6045-220M; LCSC C780213
L2: 10u; IND-SMD_L6.0-W6.0_SRN6045; Part SRN6045-100M; LCSC C476261
Q1: DMP3013SFV-7; TRANS_FDMC8010; Part DMP3013SFV-7; LCSC C264098
R1: 88.7k; R_0603; Part 0603WAF8872T5E; LCSC C23258
R2: 22.1k; R_0603; Part FRC0603F2212TS; LCSC C2960862
R3: 12k; R_0603; Part FRC0603J123 TS; LCSC C2907097
R4: 100k; R_0603; Part FRC0603F1003TS; LCSC C2906980
R5: 5.23k; R_0603; Part 0603WAF5231T5E; LCSC C23068
U4: TPS560430XDBVR; SOT-23-6_L2.9-W1.6-P0.95-LS2.8-BL; MPN TPS560430XDBVR; LCSC Part C524782
U5: TLV75533PDBVR; SOT-23-5_L3.0-W1.7-P0.95-LS2.8-BR; MPN TLV75533PDBVR; LCSC Part C404027
U6: TPS54202DDCR; SOT-23-6_L2.9-W1.6-P0.95-LS2.8-BL; MPN TPS54202DDCR; LCSC Part C191884

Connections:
3.3V: C9.1, U5.5 (OUT); also elsewhere on the board
5V: C1.1, C8.1, L1.1, R1.1, U5.1 (IN), U5.3 (EN)
12V: C11.2, C12.1, L2.2, R4.1; also elsewhere on the board
20V: C3.1, C5.1, C6.1, C7.1, C13.1, C14.1, D2.1 (C), Q1.1 (S), Q1.2 (S), Q1.3 (S), U4.4 (EN), U4.5 (VIN), U6.3 (VIN); also elsewhere on the board
/Dovod elektrike/BOOT_12: C10.2, U6.6 (BOOT)
/Dovod elektrike/CB: C4.1, U4.1 (CB)
/Dovod elektrike/FB_5: R1.2, R2.1, U4.3 (FB)
/Dovod elektrike/FB_12: C11.1, R4.2, R5.1, U6.4 (FB)
/Dovod elektrike/GATE: C5.2, D2.2 (A), Q1.4 (G), R3.1
/Dovod elektrike/SW_5: C4.2, L1.2, U4.6 (SW)
/Dovod elektrike/SW_12: C10.1, L2.1, U6.2 (SW)
/Dovod elektrike/VIN: C2.1, D1.2, J1.4, Q1.5 (D), Q1.6 (D), Q1.7 (D), Q1.8 (D)
FEN_EN: U6.5 (EN); also elsewhere on the board
GND: C1.2, C2.2, C3.2, C6.2, C7.2, C8.2, C9.2, C12.2, C13.2, C14.2, D1.1, J1.1, J1.2, J1.3, J1.6, R2.2, R3.2, R5.2, U4.2 (GND), U5.2 (GND), U6.1 (GND); also elsewhere on the board

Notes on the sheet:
zaščita proti napačni polarnosti
Alternativni del C14675
MAX 2,0 A
MAX 0,5 A
Med padoma ne sne biti zemlja.
aktiven v FLOAT
MAX 0,6 A
Vhod: 19 V min. 7,0 A

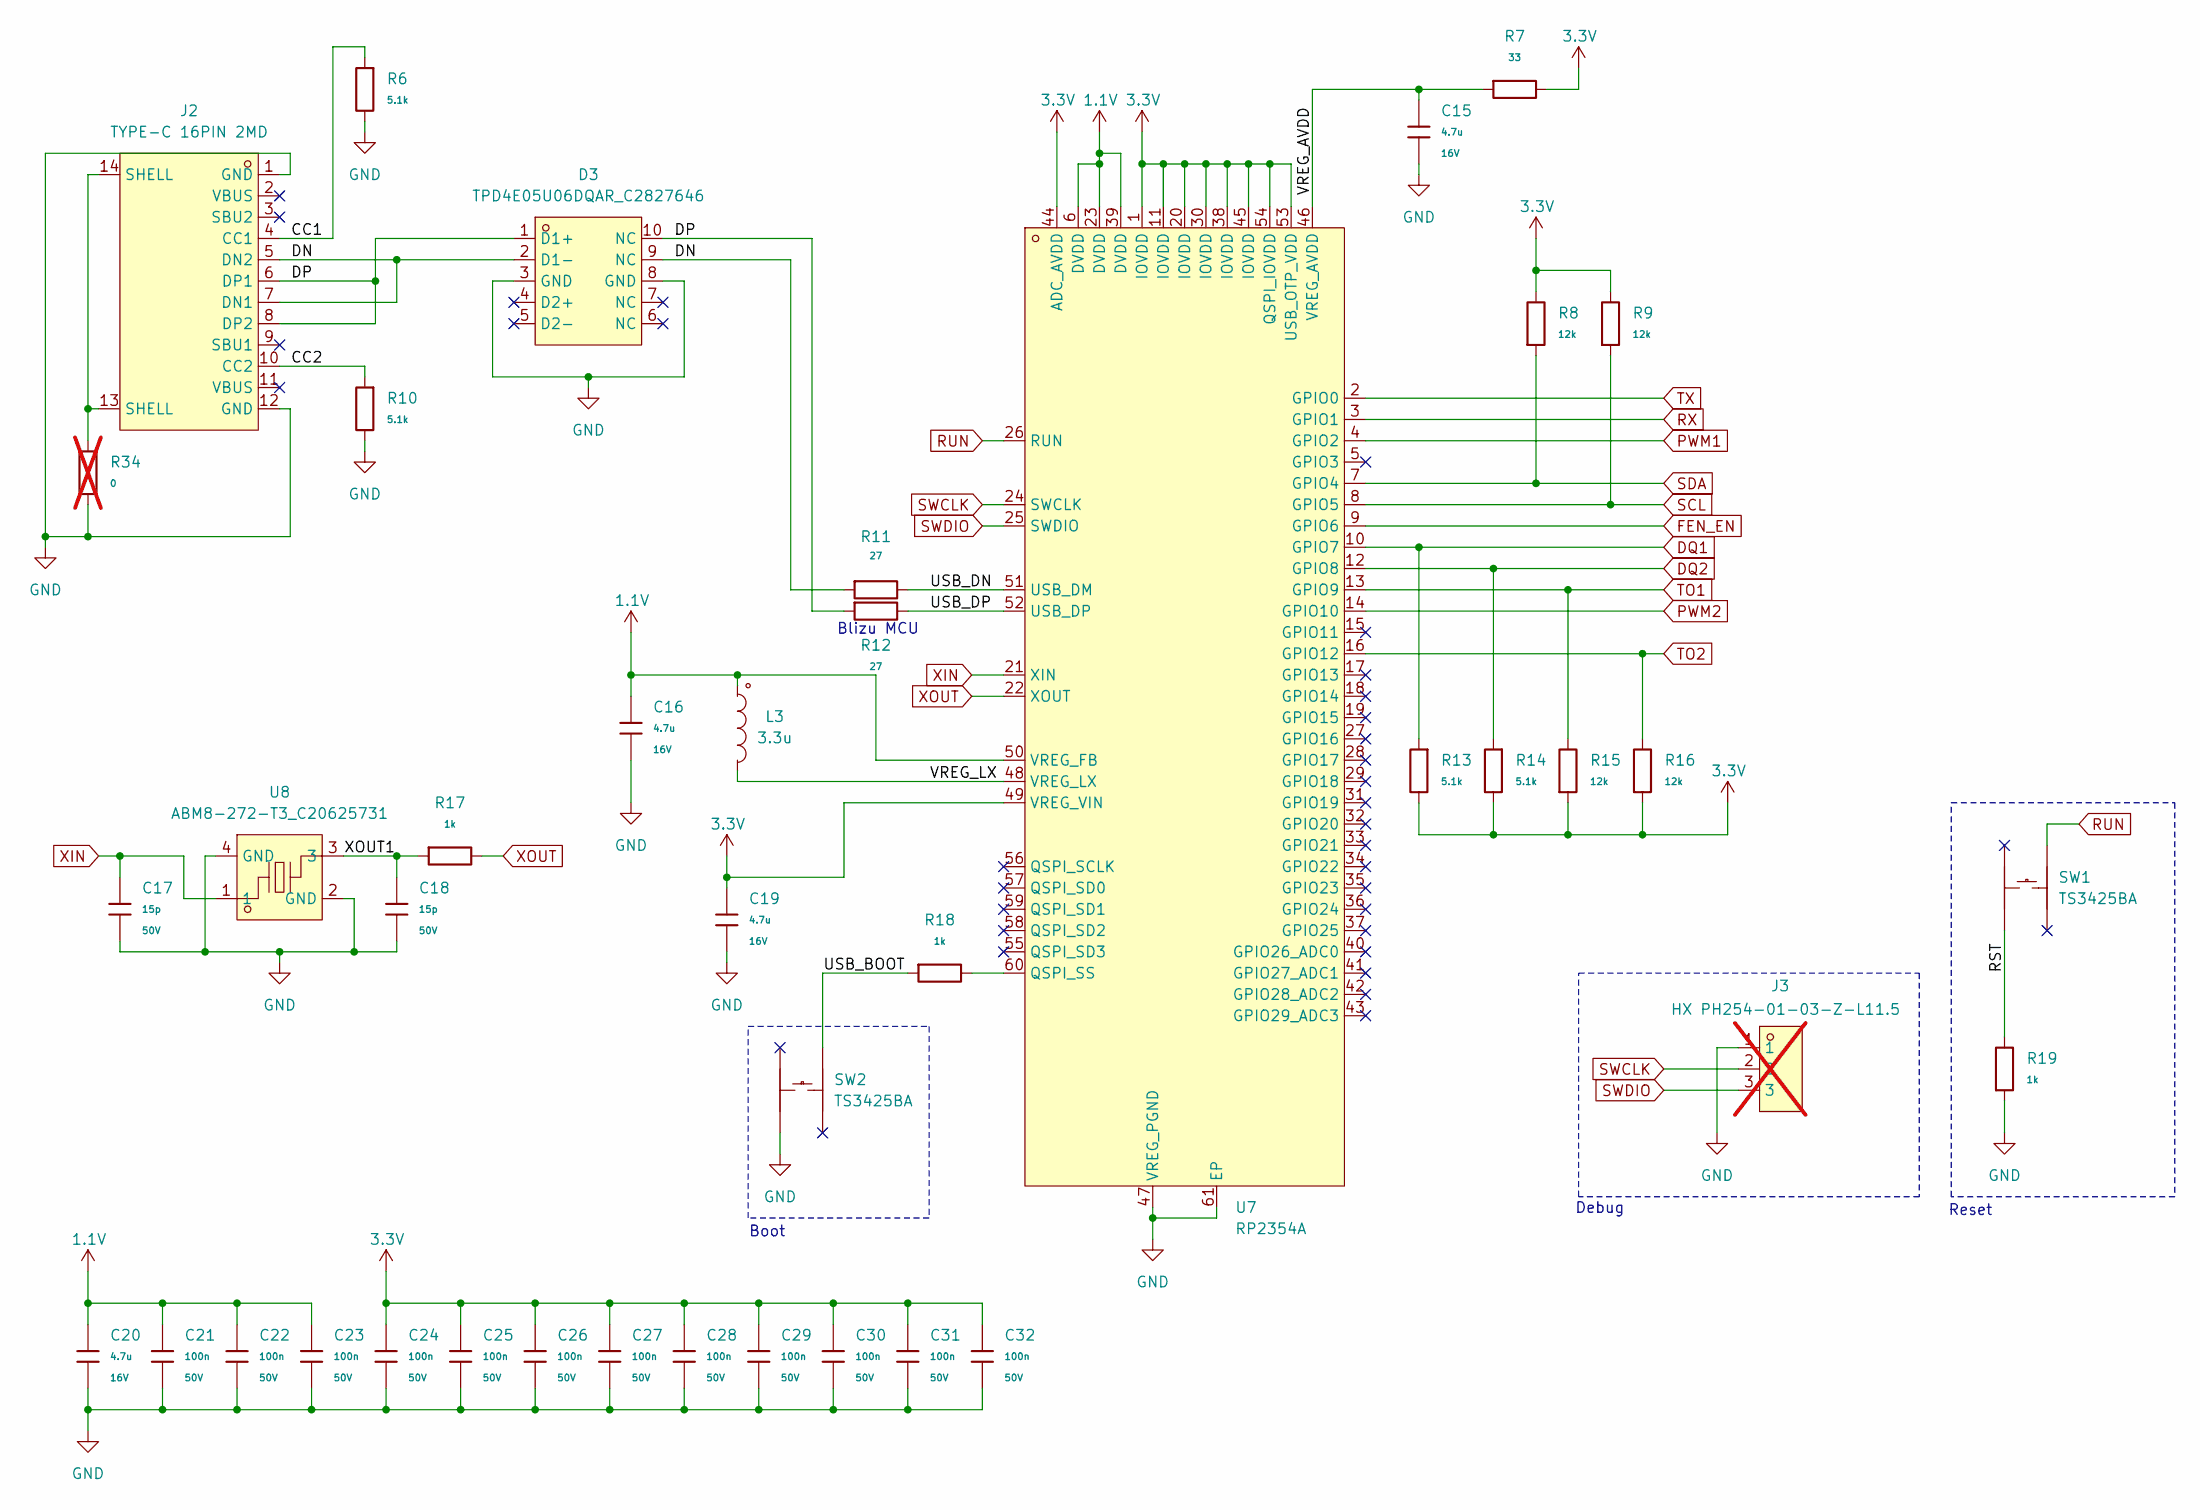
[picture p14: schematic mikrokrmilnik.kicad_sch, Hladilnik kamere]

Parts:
C15, C16, C19, C20: 4.7u; C_0603; Voltage Rated 16V; Part CL10A475KO8NNNC; LCSC C19666
C17, C18: 15p; C_0603; Voltage Rated 50V; Part CC0603FRNPO9BN150; LCSC C519483
C21, C22, C23, C24, C25, C26, C27, C28, C29, C30, C31, C32: 100n; C_0603; Voltage Rated 50V; Tolerance ±10%; Part CGA0603X7R104K500JT; LCSC C6119867
D3: TPD4E05U06DQAR_C2827646; USON-10_L2.5-W1.0-P0.50-BL; Part TPD4E05U06DQAR; LCSC C2827646
J2: TYPE-C 16PIN 2MD; USB-C-SMD_TYPE-C-6PIN-2MD-073; Part TYPE-C 16PIN 2MD(073); LCSC C2765186
J3: HX PH254-01-03-Z-L11.5; HDR-TH_3P-P2.54-V-M-1; MPN HX PH254-01-03-Z-L11.5 pcb pin header; LCSC Part C52016391; not fitted
L3: 3.3u; IND-SMD_L2.0-W1.6_AOTA-B201610S3R3-101-T; Part AOTA-B201610S3R3-101-T; LCSC C42411119
R6, R10, R13, R14: 5.1k; R_0603; Part FRC0603F5101TS; LCSC C2907044
R7: 33; R_0603; Part FRC0603F33R0TS; LCSC C2909394
R8, R9, R15, R16: 12k; R_0603; Part FRC0603J123 TS; LCSC C2907097
R11, R12: 27; R_0603; Part FRC0603F27R0TS; LCSC C2907021
R17, R18, R19: 1k; R_0603; Part FRC0603F1001TS; LCSC C2907002
R34: 0; R_0603; Part FRC0603F0000TS; LCSC C2906974; not fitted
SW1, SW2: TS3425BA; SW-SMD_4P-L4.2-W3.2-P2.15-LS4.6-1; Part TS3425BA; LCSC C2681476
U7: RP2354A; QFN-60_L7.0-W7.0-P0.40-TL-EP3.4; Part RP2354A; LCSC C41378174
U8: ABM8-272-T3_C20625731; CRYSTAL-SMD_4P-L3.2-W2.5-BL; MPN ABM8-272-T3; LCSC Part C20625731

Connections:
1.1V: C16.1, C20.1, C21.1, C22.1, C23.1, L3.2, U7.6 (DVDD), U7.23 (DVDD), U7.39 (DVDD), U7.50 (VREG_FB)
3.3V: C19.2, C24.1, C25.1, C26.1, C27.1, C28.1, C29.1, C30.1, C31.1, C32.1, R7.1, R8.1, R9.1, R13.1, R14.1, R15.2, R16.2, U7.1 (IOVDD), U7.11 (IOVDD), U7.20 (IOVDD), U7.30 (IOVDD), U7.38 (IOVDD), U7.44 (ADC_AVDD), U7.45 (IOVDD), U7.49 (VREG_VIN), U7.53 (USB_OTP_VDD), U7.54 (QSPI_IOVDD); also elsewhere on the board
/Mikrokrmilnik/CC1: J2.4 (CC1), R6.2
/Mikrokrmilnik/CC2: J2.10 (CC2), R10.2
/Mikrokrmilnik/DN: D3.2 (D1-), D3.9 (NC), J2.5 (DN2), J2.7 (DN1), R11.2
/Mikrokrmilnik/DP: D3.1 (D1+), D3.10 (NC), J2.6 (DP1), J2.8 (DP2), R12.2
/Mikrokrmilnik/RST: R19.1, SW1.4
/Mikrokrmilnik/USB_BOOT: R18.2, SW2.1
/Mikrokrmilnik/USB_DN: R11.1, U7.51 (USB_DM)
/Mikrokrmilnik/USB_DP: R12.1, U7.52 (USB_DP)
/Mikrokrmilnik/VREG_AVDD: C15.1, R7.2, U7.46 (VREG_AVDD)
/Mikrokrmilnik/VREG_LX: L3.1, U7.48 (VREG_LX)
/Mikrokrmilnik/XOUT1: C18.1, R17.2, U8.3
DQ1: R13.2, U7.10 (GPIO7); also elsewhere on the board
DQ2: R14.2, U7.12 (GPIO8); also elsewhere on the board
FEN_EN: U7.9 (GPIO6); also elsewhere on the board
GND: C15.2, C16.2, C17.2, C18.2, C19.1, C20.2, C21.2, C22.2, C23.2, C24.2, C25.2, C26.2, C27.2, C28.2, C29.2, C30.2, C31.2, C32.2, D3.3 (GND), D3.8 (GND), J2.1 (GND), J2.12 (GND), J3.1, R6.1, R10.1, R19.2, R34.1, SW2.4, U7.47 (VREG_PGND), U7.61 (EP), U8.2 (GND), U8.4 (GND); also elsewhere on the board
unnamed: J2.13 (SHELL), J2.14 (SHELL), R34.2
unnamed: R18.1, U7.60 (QSPI_SS)
PWM1: U7.4 (GPIO2); also elsewhere on the board
PWM2: U7.14 (GPIO10); also elsewhere on the board
RUN: SW1.1, U7.26 (RUN)
RX: U7.3 (GPIO1)
SCL: R9.2, U7.8 (GPIO5); also elsewhere on the board
SDA: R8.2, U7.7 (GPIO4); also elsewhere on the board
SWCLK: J3.2, U7.24 (SWCLK)
SWDIO: J3.3, U7.25 (SWDIO)
TO1: R15.1, U7.13 (GPIO9); also elsewhere on the board
TO2: R16.1, U7.16 (GPIO12); also elsewhere on the board
TX: U7.2 (GPIO0)
XIN: C17.1, U7.21 (XIN), U8.1
XOUT: R17.1, U7.22 (XOUT)

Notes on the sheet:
Boot
Debug
Reset
Blizu MCU

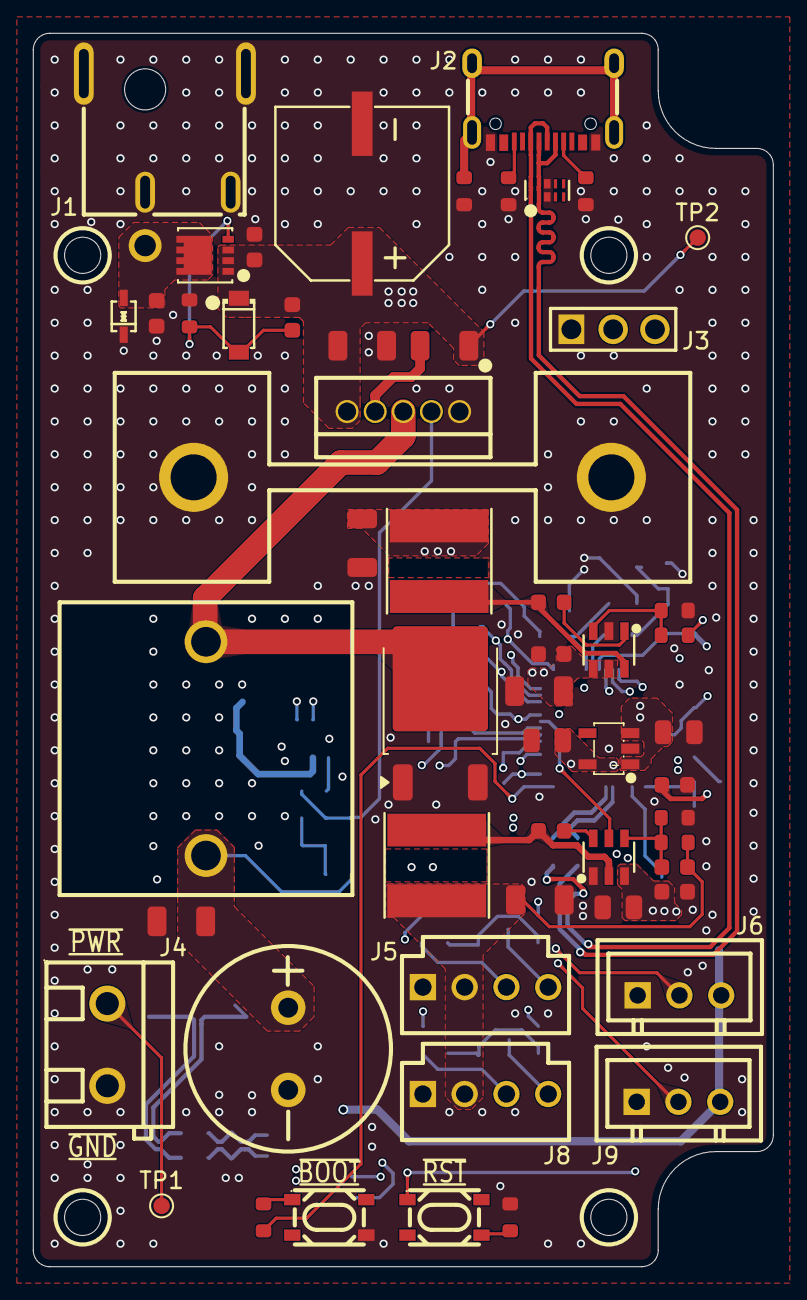
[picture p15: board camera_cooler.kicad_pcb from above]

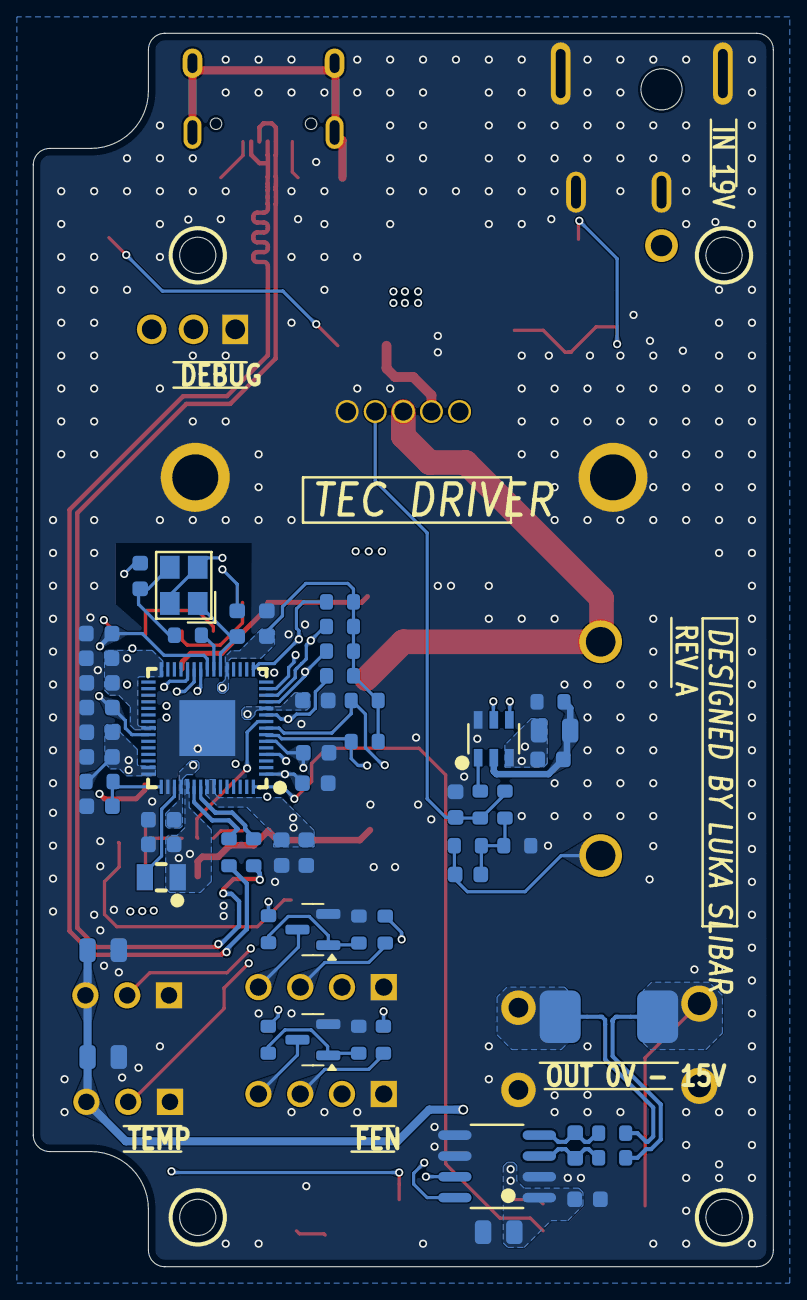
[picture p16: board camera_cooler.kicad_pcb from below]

Board: 4 copper layers, 45.0 x 75.0 mm, 118 parts (59 on the bottom side), 59 nets.

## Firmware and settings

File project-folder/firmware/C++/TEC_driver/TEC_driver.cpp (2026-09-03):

// Program, ki vključuje PID regulacijo za nadziranje temperature paltierovega elementa.

#include <iostream>
#include <string>
#include <array>
#include <cassert>
#include <sstream>
#include "pico/stdlib.h"
#include "hardware/i2c.h"
#include "hardware/pio.h"
#include "hardware/pwm.h"
#include "ina219.h"
#include "pwm_fans.h"
#include "pid_constants.h"
#include "onewire_library.h"
#include "ow_rom.h"
#include "ds18b20.h"

using uint = unsigned int;

// I2C
constexpr uint SDA_PIN = 4;
constexpr uint SCL_PIN = 5;
// DAC
constexpr std::uint8_t DAC_ADDRESS = 0x60;
constexpr double VDD = 3.3;

bool write_DAC(double DAC_voltage)
{
    std::uint16_t Dn = static_cast<std::uint16_t>((DAC_voltage * 4095.0) / VDD);
    std::array<std::uint8_t, 2> buf;
    buf[0] = (Dn >> 8) & 0x0F;
    buf[1] = Dn & 0xFF;

    int ret = i2c_write_blocking(i2c0, DAC_ADDRESS, buf.data(), buf.size(), false);
    if (ret != 2) {
        std::cout << "I2C error: DAC write failed (ret=" << ret << ").\n";
        return false;
    }
    return true;
}

bool config_ina(std::uint8_t reg, std::uint16_t value)
{
    std::array<std::uint8_t, 3> buf = {reg, static_cast<std::uint8_t>(value >> 8), static_cast<std::uint8_t>(value & 0xFF)};
    int ret = i2c_write_blocking(i2c0, ina219::ADDRESS, buf.data(), buf.size(), false);
    if (ret != 3) {
        std::cout << "I2C error: INA219 config failed (ret=" << ret << ").\n";
        return false;
    }
    return true;
}

uint16_t read_ina(std::uint8_t reg)
{
    int ret = i2c_write_blocking(i2c0, ina219::ADDRESS, &reg, 1, true);
    if (ret != 1) {
        std::cout << "I2C error: INA219 register select failed.\n";
        return 0; // sentinel - klicatelj naj ve da je to lahko neveljavno
    }

    std::array<std::uint8_t, 2> buf;
    ret = i2c_read_blocking(i2c0, ina219::ADDRESS, buf.data(), buf.size(), false);
    if (ret != 2) {
        std::cout << "I2C error: INA219 read failed.\n";
        return 0;
    }

    return static_cast<std::uint16_t>(buf[0] << 8) | buf[1];
}

double calculate_ina(std::string measurement)
    /* argumenti: vin_v, vbus_v, vshunt_mv, ma, mw
    glede na željeno meritev jo izračuna in vrne */
{
    std::uint16_t bus_raw = read_ina(ina219::REG_BUSVOLT);
    double vbus_v = (bus_raw >> 3) * ina219::VBUS_LSB_MV / 1000.0;

    if (bus_raw & ina219::BUSVOLT_OVF)
        std::cout << "Math overflow - out of range.\n";

    if (measurement == "vin_v"){
        double vshunt_mv = static_cast<std::int16_t>(read_ina(ina219::REG_SHUNTVOLT)) * ina219::VSHUNT_LSB_MV;
        double vin_v = vbus_v + vshunt_mv / 1000.0; // vin_v je + na strani porabnika
        return vin_v;
    }
    else if (measurement == "vshunt_mv"){
        double vshunt_mv = static_cast<std::int16_t>(read_ina(ina219::REG_SHUNTVOLT)) * ina219::VSHUNT_LSB_MV; //10 µV/LSB
        return vshunt_mv;
    }
    else if (measurement == "vbus_v"){
        return vbus_v; // vbus_v je na strani napajanja
    }
    else if (measurement == "ma"){
        double ma = static_cast<std::int16_t>(read_ina(ina219::REG_CURRENT)) * ina219::CURRENT_LSB_MA; // CURRENT_LSB_MA mA/LSB
        return ma;
    }
    else if (measurement == "mw"){
        double mw = read_ina(ina219::REG_POWER) * ina219::POWER_LSB_MW; // le pozitivna, POWER_LSB_MW mW/LSB
        return mw;
    }

    return 0.0;
}

namespace {
    bool fan1_on = false; // lahko v 2 funkcijah uporabljam
    bool fan2_on = false;
}

void update_fan_enable()
{
    if (fan1_on || fan2_on){
        gpio_set_dir(pwmfan::FEN_EN, GPIO_IN);
        gpio_set_pulls(pwmfan::FEN_EN, false, false); // HiZ -> omogoči
    }
    else{
        gpio_set_dir(pwmfan::FEN_EN, GPIO_IN);
        gpio_set_pulls(pwmfan::FEN_EN, false, true); // pull-down -> onemogoči
    }
}

void fan_control(bool on, int pwm_pin, uint duty_cycle)
{
    gpio_set_function(pwm_pin, GPIO_FUNC_PWM);
    gpio_init(pwmfan::FEN_EN);

    uint slice_st = pwm_gpio_to_slice_num(pwm_pin);
    uint channel = pwm_gpio_to_channel(pwm_pin);
    std::uint32_t clock = clock_get_hz(clk_sys);

    std::uint8_t duty_cyclet = 100 - duty_cycle;
    uint wrap = clock / pwmfan::FREQ - 1;
    uint level = (duty_cyclet * (wrap + 1)) / 100;

    gpio_set_outover(pwm_pin, GPIO_OVERRIDE_NORMAL);
    pwm_set_clkdiv(slice_st, 1.0);
    pwm_set_wrap(slice_st, wrap);
    pwm_set_chan_level(slice_st, channel, level);

    // posodobi stanje samo za ventilator, ki ga ta klic zadeva
    if (pwm_pin == static_cast<int>(pwmfan::PIN1))
        fan1_on = on;
    else if (pwm_pin == static_cast<int>(pwmfan::PIN2))
        fan2_on = on;

    if (on)
        pwm_set_enabled(slice_st, true);
    else{
        gpio_set_outover(pwm_pin, GPIO_OVERRIDE_LOW);
        pwm_set_enabled(slice_st, false);
    }

    update_fan_enable(); // FEN_EN se zdaj postavi glede na oba ventilatorja
}

bool init_ds18b20(OW* ow, PIO pio, uint offset)
{
    if (!ow_init(ow, pio, offset, ds18b20::PIN2)){
        std::cout << "Initialization of OW on GPIO " << ds18b20::PIN2 << " failed!\n"; // za enkrat naj bo le en termometer
        return false;
    }

    if (!ow_reset(ow)){
        std::cout << "DS18B20 on GPIO " << ds18b20::PIN2 << " not found!\n";
        return false;
    }

    return true;
}

double read_ds18b20(OW* ow) // * -> pričakuje kazalec
    // prebere vrednost na izbranem termometru in vrne temperaturo v °C
{
    ow_reset(ow);
    ow_send(ow, ow::SKIP_ROM); // samo 1 naprava na enem busu
    ow_send(ow, ds18b20::CONVERT_T);

    sleep_ms(750);
    //while (ow_read(ow) == 0) // ko je pretvorba končna ds18b20 vrne 1 -> zaključi zanko

    ow_reset(ow);
    ow_send(ow, ow::SKIP_ROM);
    ow_send(ow, ds18b20::READ_SCRATCHPAD);

    std::uint8_t lsb = ow_read(ow);
    std::uint8_t msb = ow_read(ow);

    std::int16_t raw_temperature = static_cast<std::int16_t>(static_cast<std::uint16_t>(msb) << 8 | lsb);

    return raw_temperature / 16.0;
}

bool is_valid_int(const std::string& s)
    // preverjanje če je pravilen vnos
{
    if (s.empty())
        return false;

    std::size_t start = (s[0] == '-' || s[0] == '+') ? 1 : 0; // if/else izniči predznak
    if (start == s.size()) // sam predznak brez številk
        return false;

    for (std::size_t i = start; i < s.size(); ++i){
        if (!std::isdigit(static_cast<unsigned char>(s[i])))
            return false;
    }
    return true;
}

bool is_valid_double(const std::string& s)
    // preverjanje če je pravilen vnos
{
    if (s.empty())
        return false;

    std::size_t i = 0;
    if (s[i] == '-' || s[i] == '+') // izpusti predznak
        ++i;

    bool has_digits = false;
    bool has_dot = false;

    for (; i < s.size(); ++i) {
        if (std::isdigit(static_cast<unsigned char>(s[i]))){
            has_digits = true;
        }
        else if (s[i] == '.' && !has_dot)
            has_dot = true;
        else
            return false;
    }
    return has_digits;
}

bool read_USB(std::array<std::string, 4>& usb_data)
{
    static std::string raw_data;
    int c;
    int chars_read = 0;
    constexpr int MAX_CHARS_PER_CALL = 512;
    constexpr std::size_t MAX_LINE_LEN = 128; // preprečim da se spomin zapolni

    while ((c = getchar_timeout_us(0)) != PICO_ERROR_TIMEOUT){
        if (c == '\n'){
            std::stringstream ss(raw_data);
            raw_data.clear();

            for (std::size_t i = 0; i < usb_data.size(); ++i){
                if (!std::getline(ss, usb_data[i], ','))
                    return false;
            }

            if (usb_data[0] != "SET")
                return false;

            if (!is_valid_int(usb_data[2])){
                std::cout << "Invalid fan number in USB data.\n";
                return false;
            }

            int fan = std::stoi(usb_data[2]); // varno, ker smo že preverili is_valid_int

            if (fan == 1)
                usb_data[2] = std::to_string(pwmfan::PIN1);
            else if (fan == 2)
                usb_data[2] = std::to_string(pwmfan::PIN2);
            else
                return false;

            std::cout << "ACK\n" << std::flush;
            return true;
        }

        raw_data += static_cast<char>(c);

        if (raw_data.size() > MAX_LINE_LEN){
            std::cout << "USB line too long, discarding.\n";
            raw_data.clear();
        }

        if (++chars_read > MAX_CHARS_PER_CALL){
            break;
        }
    }

    return false;
}

double pid_controller(double temp_current, double temp_desired, bool reset_integral)
{
    static double previous_error = 0.0;
    static double integral = 0.0;
    static bool first_run = true;

    if (reset_integral){
        integral = 0.0;
        first_run = true; // da se tudi odvod ne izračuna napačno na naslednjem klicu
    }

    double error = temp_current - temp_desired;

    if (first_run){
        previous_error = error;
        first_run = false;
    }

    double derivative = (error - previous_error) / pid::dT;

    // izračunaj izhod brez posodobitve integrala, da lahko preverimo nasičenost
    double DAC_voltage = VDD - (pid::Kp * error + pid::Ki * integral + pid::Kd * derivative);

    bool saturated_high = (DAC_voltage >= VDD);
    bool saturated_low  = (DAC_voltage <= 0.4); // omejitev

    /* integral posodobi samo, če izhod ni nasičen,
    ali če bi posodobitev integrala pomagala izhod premakniti stran od nasičenosti */
    bool integrating_would_help =
    (saturated_low  && error < 0.0) ? false :
    (saturated_high && error > 0.0) ? false :
    true;

    if (integrating_would_help){
        integral += error * pid::dT;
        DAC_voltage = VDD - (pid::Kp * error + pid::Ki * integral + pid::Kd * derivative); // ponovno izračunaj izhod s posodobljenim integralom
    }

    // omejitev izhoda DAC-a
    if (DAC_voltage > VDD)
        DAC_voltage = VDD;
    else if (DAC_voltage < 0.4)
        DAC_voltage = 0.4;

    previous_error = error;
    return DAC_voltage;
}

int main()
{
    stdio_init_all();
    sleep_ms(2000); // počakaj, da se odpre USB Serial
    i2c_init(i2c0, 100000);
    gpio_set_function(SDA_PIN, GPIO_FUNC_I2C);
    gpio_set_function(SCL_PIN, GPIO_FUNC_I2C);

    // OneWire konfiguracija
    PIO pio = pio0;
    uint offset;
    if (!pio_can_add_program(pio, &onewire_program)){
        std::cout << "Could not add 1-Wire PIO program.\n";
        return 1;
    }
    offset = pio_add_program(pio, &onewire_program);
    OW ow1;
    //OW ow2; za enkrat le en termometer
    if (!init_ds18b20(&ow1, pio, offset)){
        std::cout << "Could not initializate the DS18B20.\n";
        return 2;
    }

    // INA219 konfiguracija
    config_ina(ina219::REG_CONFIG, ina219::CONFIG_VALUE);
    config_ina(ina219::REG_CALIBRATION, ina219::CALIBRATION_VALUE);

    // sprobaj ventilatorja
    fan_control(false, pwmfan::PIN1, 0);
    fan_control(false, pwmfan::PIN2, 0);
    sleep_ms(1000);
    fan_control(true, pwmfan::PIN1, 20);
    fan_control(true, pwmfan::PIN2, 20);
    sleep_ms(1000);
    fan_control(false, pwmfan::PIN1, 0);
    fan_control(false, pwmfan::PIN2, 0);


    constexpr double STEP = 4.0;
    constexpr double STEP_TOLERANCE = 0.5;
    bool first_run = true;
    bool reset_integral_flag = false;
    double DAC_voltage = VDD; // privzeta napetost na DAC, ne hladi
    double temp_desired = 20.0; // itak se prepiše
    double temp_desired_step = 20.0; // itak se prepiše
    int timer = 0;

    while (true) {
        std::array<std::string, 4> new_usb_data;

        // za prvi krog ne nadaljuj z zanko dokler ne dobiš nastavitev
        if (first_run){
            // DAC konfiguracija
            write_DAC(DAC_voltage);

            while (true){
                while (!read_USB(new_usb_data)){

                    if (timer == 25){  // približno vsako sekundo
                        std::cout << "DATA,"
                        << read_ds18b20(&ow1) << "," // odstrani, če bo preveč blokirajoče
                        << calculate_ina("vin_v") << ","
                        << calculate_ina("ma") << ","
                        << calculate_ina("mw") << ","
                        << DAC_voltage
                        << "\n" << std::flush;

                        timer = 0;
                    }

                    ++timer;
                    sleep_ms(10); // da ni procesor popolnoma porabljen
                }

                if (is_valid_double(new_usb_data[1]) &&
                    is_valid_int(new_usb_data[2]) &&
                    is_valid_int(new_usb_data[3])){

                    temp_desired = std::stod(new_usb_data[1]);
                    uint fan_pin = static_cast<uint>(std::stoi(new_usb_data[2]));
                    uint fan_speed = static_cast<uint>(std::stoi(new_usb_data[3]));
                    fan_control(true, fan_pin, fan_speed);
                    break;
                }
                std::cout << "Invalid USB data, waiting for valid settings.\n";
            }
        }

        absolute_time_t cycle_start = get_absolute_time();

        if (!first_run){
            if (read_USB(new_usb_data)){
                if (!is_valid_double(new_usb_data[1]) ||
                    !is_valid_int(new_usb_data[2]) ||
                    !is_valid_int(new_usb_data[3])){
                    std::cout << "Invalid USB data, ignoring command.\n";
                }
                else{
                    double new_temp_desired = std::stod(new_usb_data[1]);

                    bool big_change = std::abs(new_temp_desired - temp_desired) > 10.0; // prag prilagodi po potrebi

                    temp_desired = new_temp_desired;
                    uint fan_pin = static_cast<uint>(std::stoi(new_usb_data[2]));
                    uint fan_speed = static_cast<uint>(std::stoi(new_usb_data[3]));
                    fan_control(true, fan_pin, fan_speed);

                    if (big_change)
                        reset_integral_flag = true;
                }
            }
        }

        config_ina(ina219::REG_CALIBRATION, ina219::CALIBRATION_VALUE);

        double temp_current = read_ds18b20(&ow1);

        // prepreči prehitro hlajenje tako, da haldi v korakih
        double diff_to_desired = temp_current - temp_desired;
        if (diff_to_desired < 0.0){
            // stopničasto hlajenje nima smisla
            temp_desired_step = temp_desired;
            first_run = false;
        }
        else if (first_run){
            if (diff_to_desired > STEP)
                temp_desired_step = temp_current - STEP;
            else
                temp_desired_step = temp_desired;

            first_run = false;
        }
        else{
            double diff_to_step = temp_current - temp_desired_step;

            if (diff_to_step <= STEP_TOLERANCE){
                if (diff_to_desired > STEP)
                    temp_desired_step = temp_current - STEP;
                else
                    temp_desired_step = temp_desired;
            }
            // sicer: temp_desired_step ostane nespremenjen, še nismo dosegli trenutnega koraka
        }

        DAC_voltage = pid_controller(temp_current, temp_desired_step, reset_integral_flag);
        reset_integral_flag = false;

        write_DAC(DAC_voltage);

        std::cout << "DATA,"
        << temp_current << ","
        << calculate_ina("vin_v") << ","
        << calculate_ina("ma") << ","
        << calculate_ina("mw") << ","
        << DAC_voltage
        << "\n" << std::flush;

        // predvidljiv cikel za izračune
        int64_t elapsed_us = absolute_time_diff_us(cycle_start, get_absolute_time());
        int64_t target_us = static_cast<int64_t>(pid::dT * 1000000.0);
        int64_t remaining_us = target_us - elapsed_us;

        if (remaining_us > 0) // ne čaka dodatno
            sleep_us(remaining_us);
    }

    return 0;
}

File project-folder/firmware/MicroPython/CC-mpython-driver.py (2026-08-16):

# Simple driver to control the TEC Driver PCB.
# Requires pyb_ina219 and Onewire_DS18X20 libraries.

from machine import Pin, I2C, PWM
from ina219 import INA219
import _thread
from time import sleep
import machine
import onewire
import ds18x20
import sys
import uselect

DAC_ADDR = 0x60
IDLE_VOLTAGE = 3.29

running = True

i2c = I2C(
    0,
    sda=Pin(4),
    scl=Pin(5),
    freq=400000
)

lock = _thread.allocate_lock()

ina = INA219(0.02, i2c)
ina.configure()

ds_pin = Pin(8)
ds_sensor = ds18x20.DS18X20(
    onewire.OneWire(ds_pin)
)
roms = ds_sensor.scan()

pwm = PWM(Pin(10))
pwm.freq(25000)

fan_enable = Pin(6, Pin.IN, Pin.PULL_DOWN)

last_voltage = 0.0
last_current = 0.0
last_power = 0.0
last_temp = 0.0

set_voltage_value = 0.0
set_fan_value = 0

def set_voltage(v):

    global set_voltage_value

    if v < 0:
        v = 0

    if v > 3.3:
        v = 3.3

    value = round((v * 4095) / 3.3)

    d4 = (value >> 8) & 0x0F
    d8 = value & 0xFF

    data = bytes([d4, d8])

    with lock:
        i2c.writeto(DAC_ADDR, data)

    set_voltage_value = v

def set_fan(percent):

    global set_fan_value

    if percent < 0:
        percent = 0

    if percent > 100:
        percent = 100

    duty = 100 - percent

    pwm.duty_u16(
        int(duty * 65535 / 100)
    )

    fan_enable.init(Pin.IN)

    set_fan_value = percent

def measure_task():

    global last_voltage
    global last_current
    global last_power
    global last_temp

    while running:

        try:

            with lock:
                last_voltage = ina.voltage()
                last_current = ina.current()
                last_power = ina.power()

            if len(roms) > 0:

                ds_sensor.convert_temp()
                sleep(0.8)

                t_sum = 0

                for rom in roms:
                    t_sum += ds_sensor.read_temp(rom)

                last_temp = t_sum / len(roms)

        except Exception as e:
            print("ERR,MEASURE,", e)

        sleep(0.2)

poll = uselect.poll()
poll.register(sys.stdin, uselect.POLLIN)

def process_usb():

    if not poll.poll(0):
        return

    try:

        line = sys.stdin.readline()

        if not line:
            return

        line = line.strip()

        if line.startswith("SET"):

            parts = line.split(",")

            if len(parts) != 3:
                return

            voltage = float(parts[1])
            fan = int(parts[2])

            set_voltage(voltage)
            set_fan(fan)

            print(
                "ACK,{:.3f},{}".format(
                    set_voltage_value,
                    set_fan_value
                )
            )

    except Exception as e:

        print(
            "ERR,USB,{}".format(e)
        )

_thread.start_new_thread(
    measure_task,
    ()
)

set_voltage(IDLE_VOLTAGE)
Pin(6, Pin.IN, Pin.PULL_DOWN)
set_fan(0)

print("READY")

try:

    while True:

        process_usb()

        print(
            "DATA,{:.3f},{:.2f},{:.2f},{:.2f}".format(
                last_voltage,
                last_current,
                last_power,
                last_temp
            )
        )

        sleep(1)

except KeyboardInterrupt:

    pass

finally:

    running = False

    pwm.deinit()

    set_voltage(IDLE_VOLTAGE)

    Pin(6, Pin.IN, Pin.PULL_DOWN)

    print("STOP")

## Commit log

2026-08-14 update - electrical
    [camera_cooler-B_Cu.gbr, camera_cooler-B_Mask.gbr, camera_cooler-B_Paste.gbr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]
2026-08-14 update - BOM
2026-08-14 update - 3dmodels, gif
    [camera-cooler-enclosure-cover.STL, camera-cooler-enclosure.STL, camera-cooler.STL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]
2026-08-16 Update README.md File naming
    [camera-cooler-cover.STL, cooling-block-holder.STL]
2026-09-03 Update Added 3d printed part
    [fan-spacer-TPU.STL]
